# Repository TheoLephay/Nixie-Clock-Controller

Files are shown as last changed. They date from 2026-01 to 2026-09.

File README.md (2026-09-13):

# Nixie clock - Divergence Meter

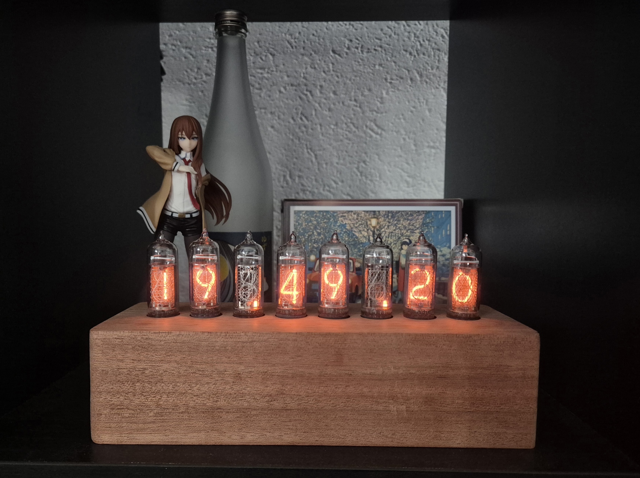
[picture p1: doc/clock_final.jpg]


I wanted to make a 8-tube design to match Steins Gate's divergence meter and to have more display capabilities.

This is build with original IN-14 (180VDC) Nixie tubes manufactured in the 70s in the Soviet Union.

## How to use

- On power on, if a wifi access point has been provided before, it will try to connect to it.
- Otherwise (if no AP, or if connection fails) it will display blinking dots and it will turn into an access point named "ESP32_Nixie".
  Connect to it, open the clock's IP on a web page, and provide wifi SSID and password. The clock will then
  try to connect to the provided wifi AP.
- It will start displaying the time. You can press the toggle swith (long or short press) to change modes.

## How to build

There should be most of the design files for software and hardware to reproduce it.

Except:
- Tubes that I bought on Ebay
- The BOM is not exaclty complete but all the electronics to build the PCB are there. What's missing is
    - the Molex ribbon cables (check the reference of the connectors and find the matching ones)
    - few pin headers and jumpers
- The case that is home made with some very specific tools.

---

## Hardware

See hardware/*.pdf for the design sheet and layer views. All Kicad design files should be present to build them and the gerber files.

key facts:

- Made for 8 IN-14 tubes
- HV DCDC generator made on board, based on [this design](https://nick.desmith.net/Electronics/NixiePSU.html)
- HV open drain shift registers HV5622 (no multiplexing)
- ESP32C3 module
- Most of the components are solderable with a soldering iron (except the ESP32 because of the pads underneath, heat gun or hot plate required + stencil)

#### Version 1.1 updates:

Fixed HV5622 footprint, used a bigger DCDC FET (Vds rated >250V), Reduced GPIO9 cap size to avoid starting in DL mode, and added PD resistors to the level shifters' NFETs.

### Issues

The feedback line of the DCDC is picking up noise which creates a visible dimming oscillation at around 20Hz (50Vpp). At high load it even makes the DCDC saturate.
I fixed it by adding a small cap (100pF) on FB pin. 0603 size is perfect to sit between SHDN and FB pins of the MAX1771.

My DCDC has only a ~70% efficiency which is not super good compared to the original design (85%), I probably did a poor layout job. But in practice it does not matter since currents involved are small.

## Software

key facts:

- Using ESP-IDF VSCode extension v5.2.1
- Programming via UART (two buttons on the board to get the ESP in download mode)
- Has a "maintenance" routine timer to cycle the cathodes lit to prevent cathode poisonning.

More modes to be coming (with a connected weather station it will be able to display temp/HR...).

- main/src/Connectivity.c - wifi state machine, mDNS & SNTP setup.
- main/src/HV5622.c - Bit banging shift register driver.
- main/src/ModeSwitch.c - Driver for the toggle switch.
- main/src/NixieDisplay.c - simple driver to display data on the 8 tubes using the shift registers.
- main/src/NixieHttpServer.c - Web control page
- main/src/SmartClock.c - core logic of the clock to display time, handle different modes.
- main/src/Storage.c - NVS wrapper for storing wifi credentials.

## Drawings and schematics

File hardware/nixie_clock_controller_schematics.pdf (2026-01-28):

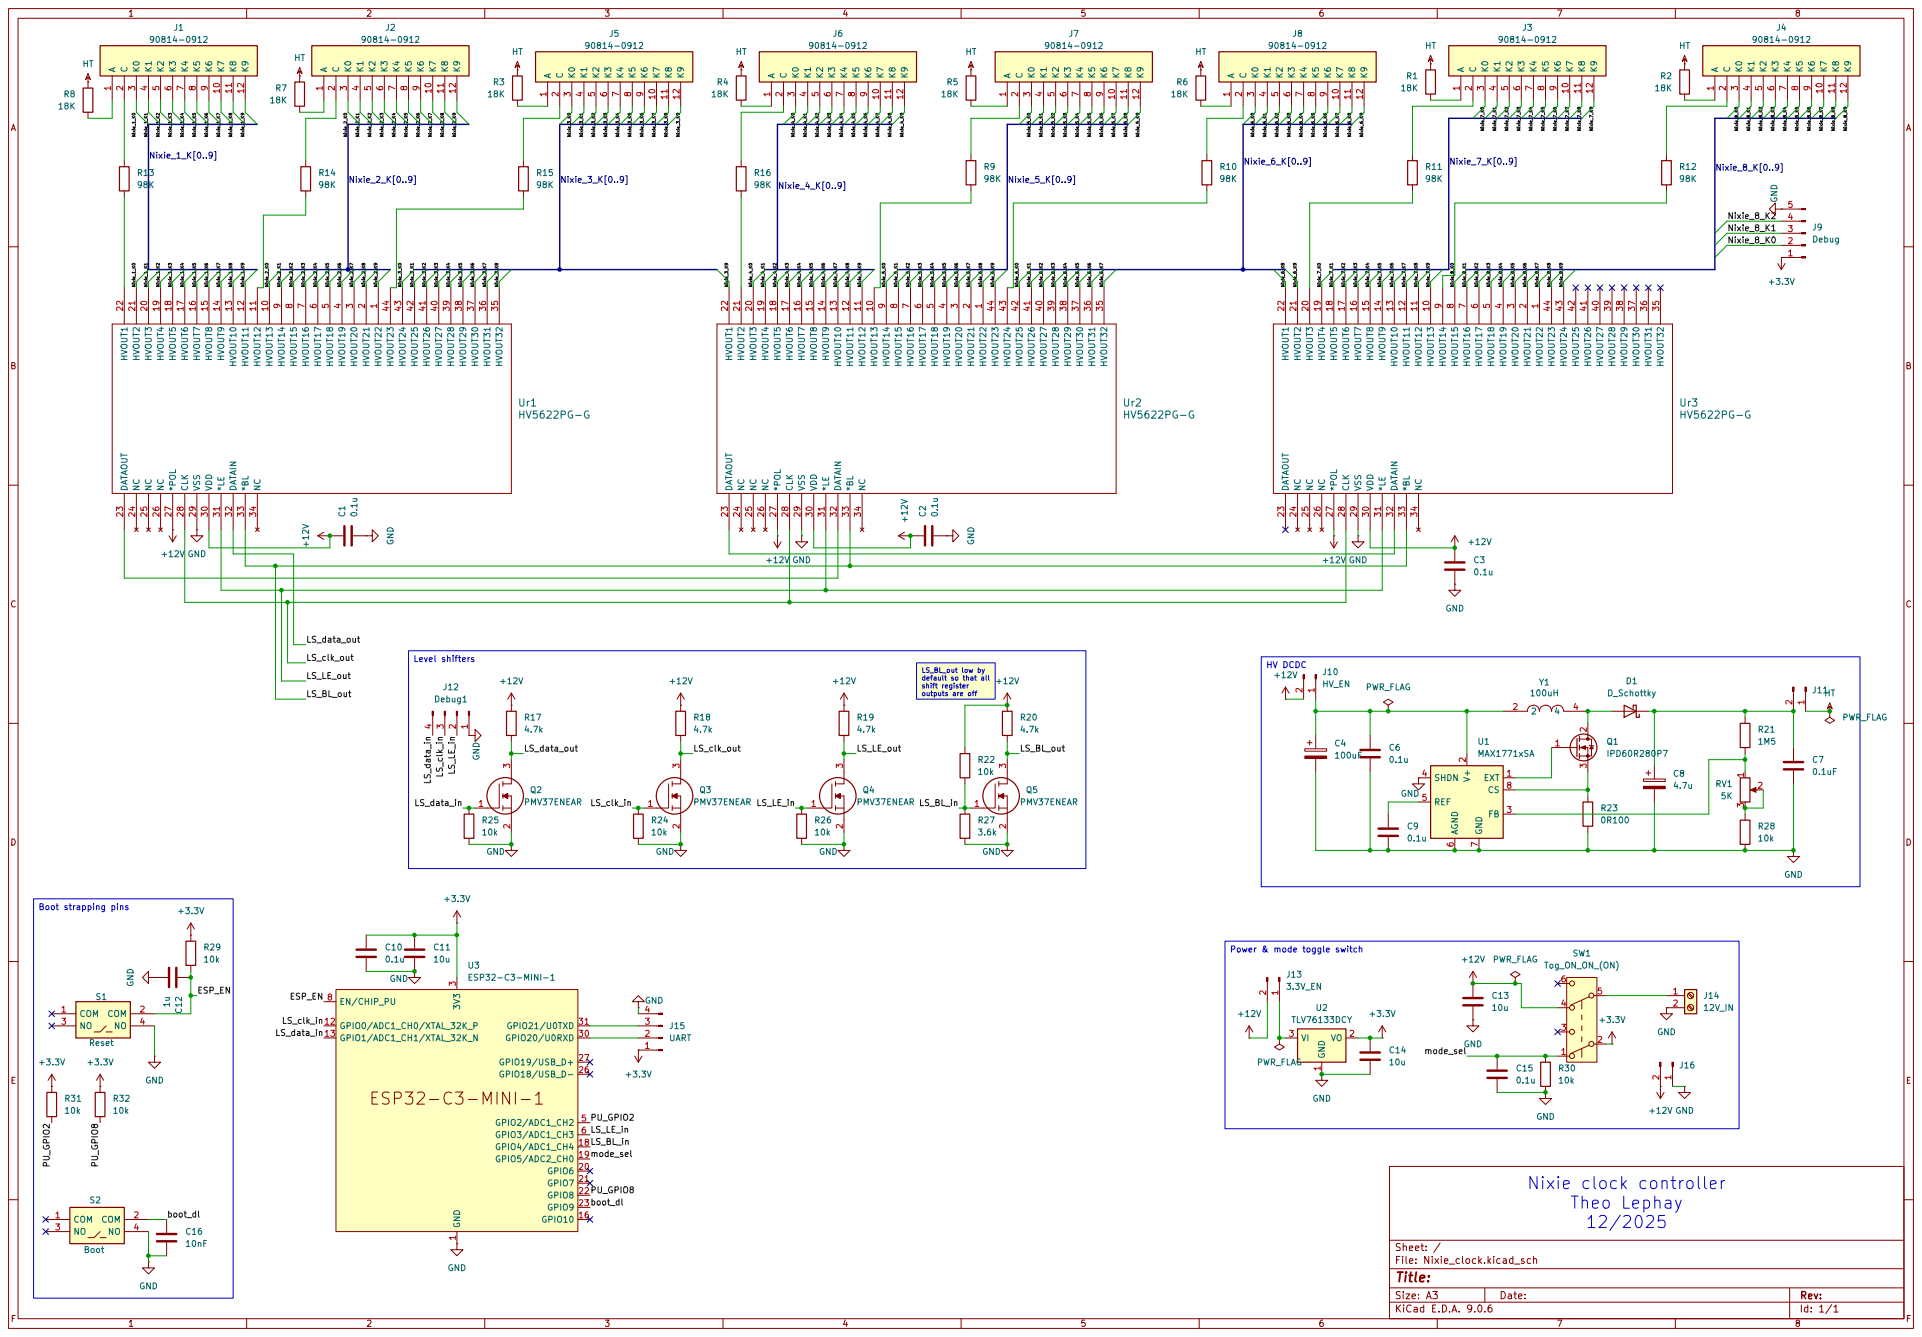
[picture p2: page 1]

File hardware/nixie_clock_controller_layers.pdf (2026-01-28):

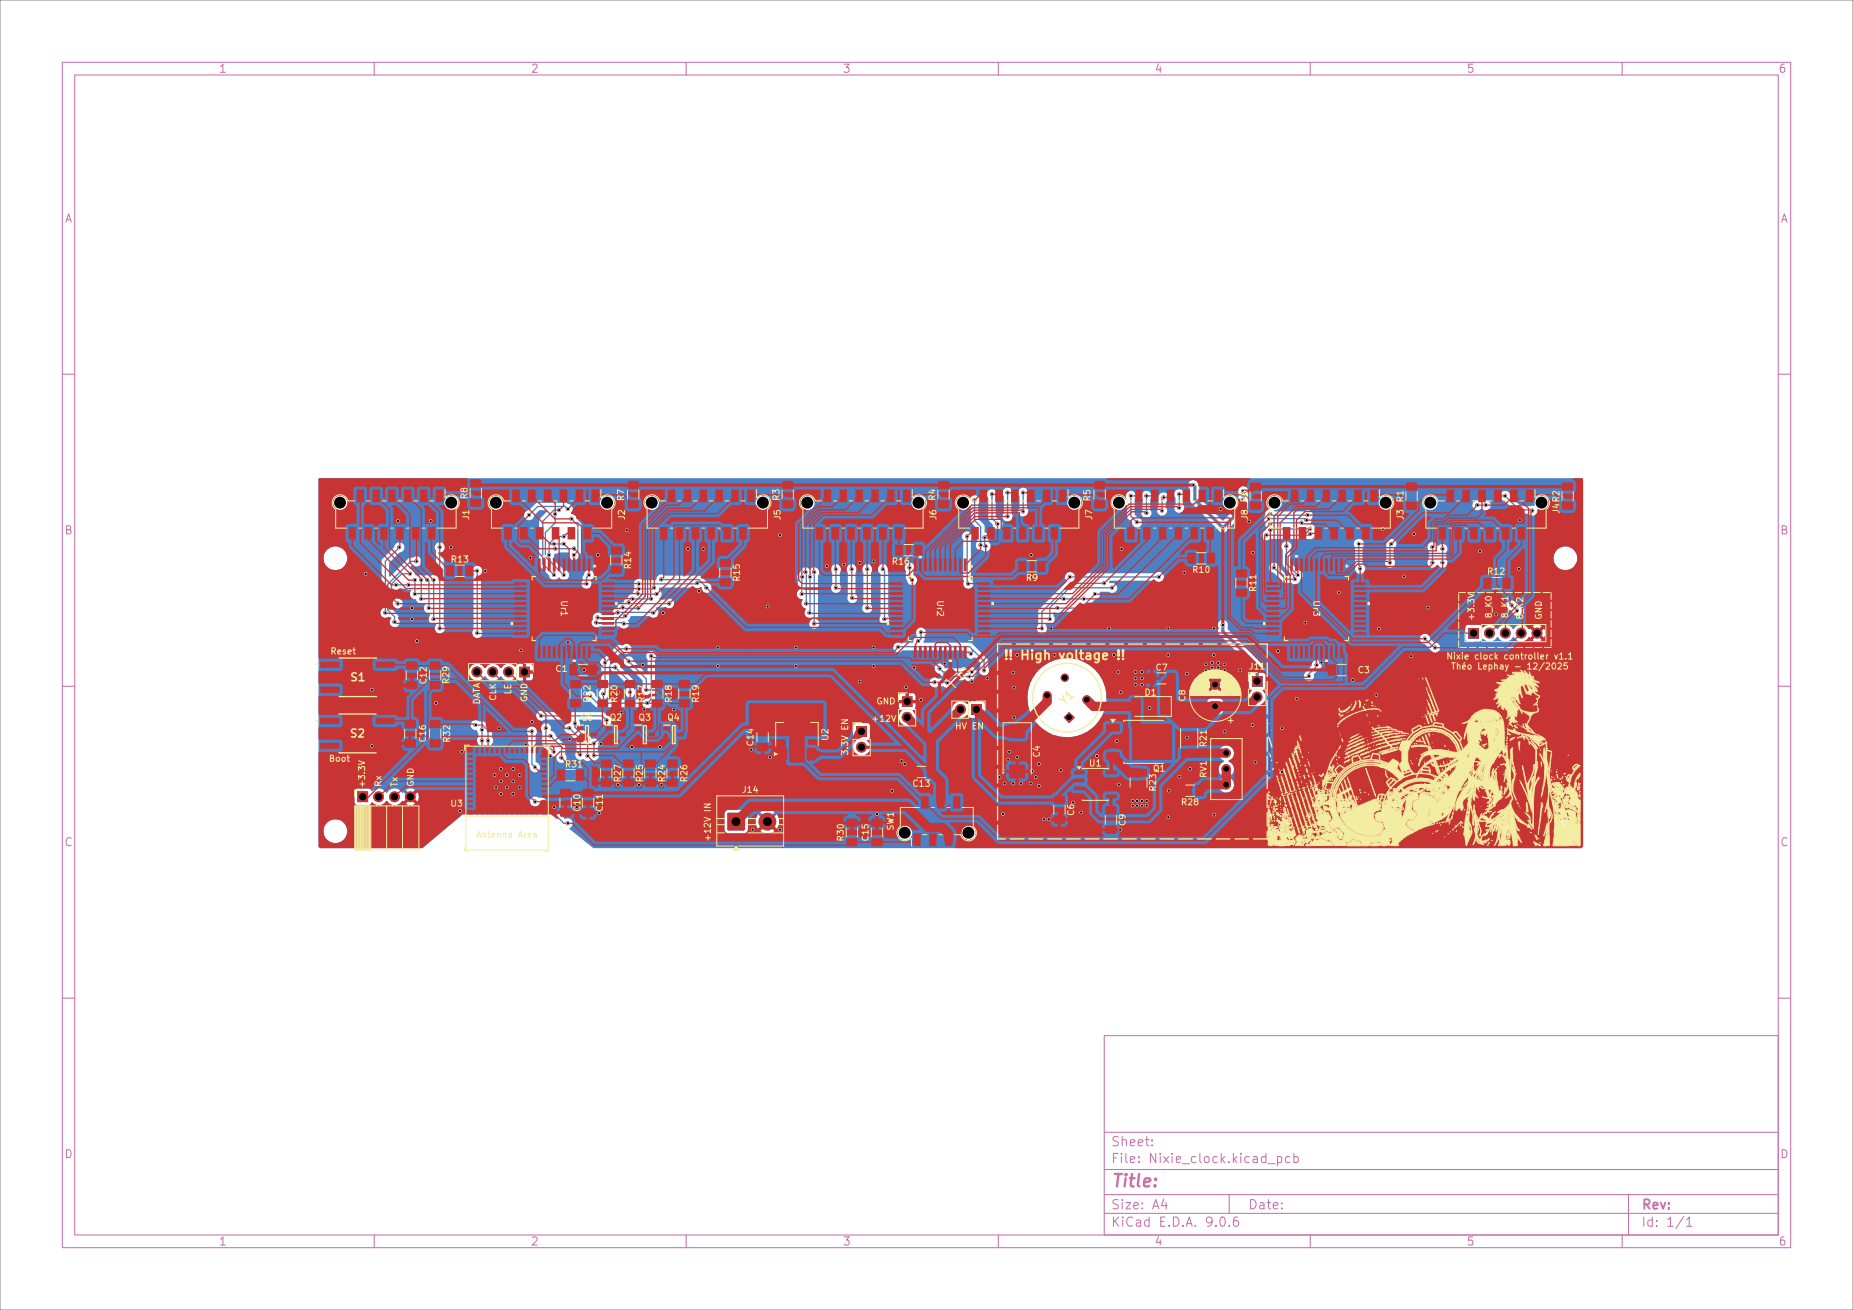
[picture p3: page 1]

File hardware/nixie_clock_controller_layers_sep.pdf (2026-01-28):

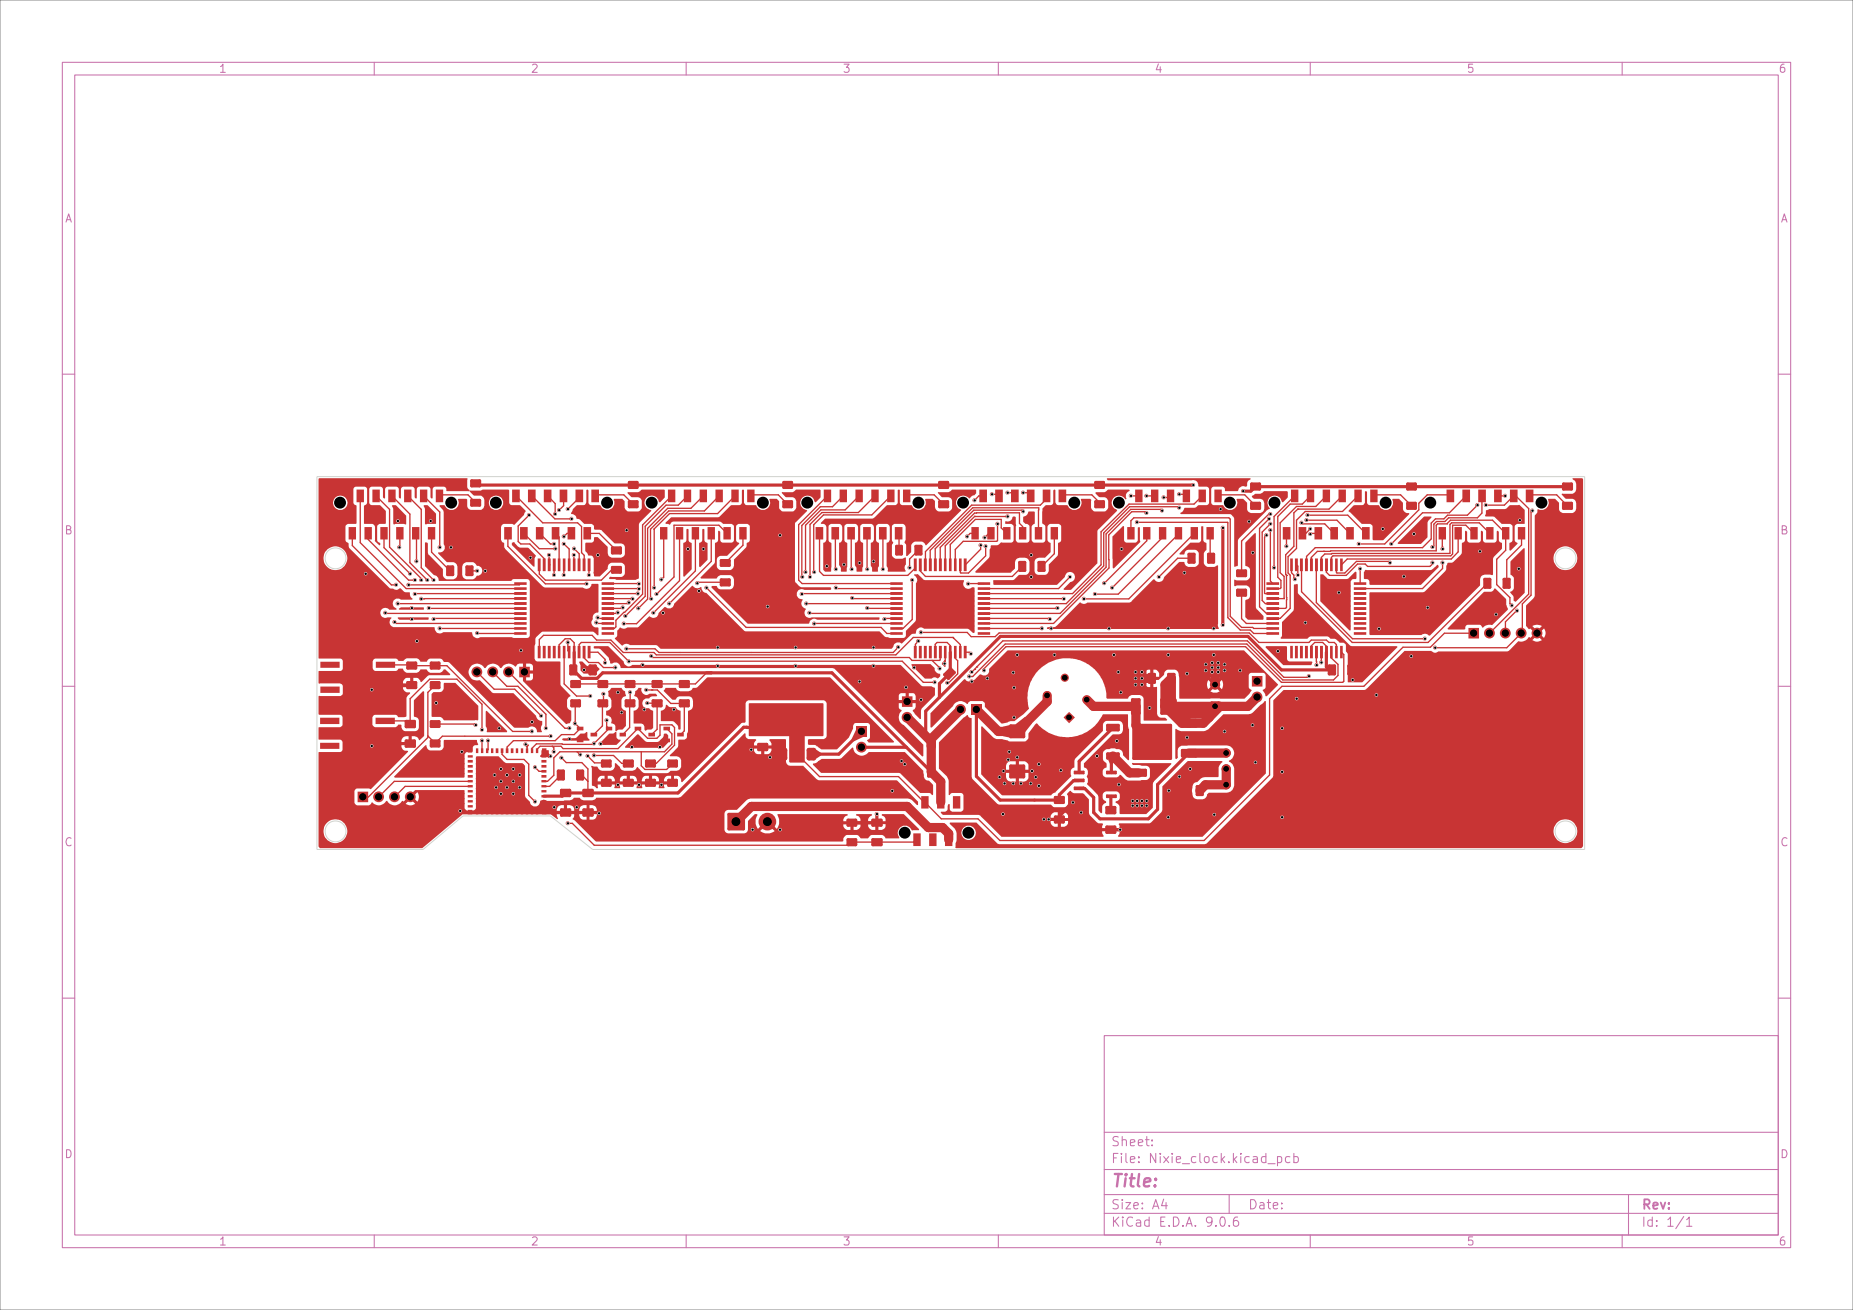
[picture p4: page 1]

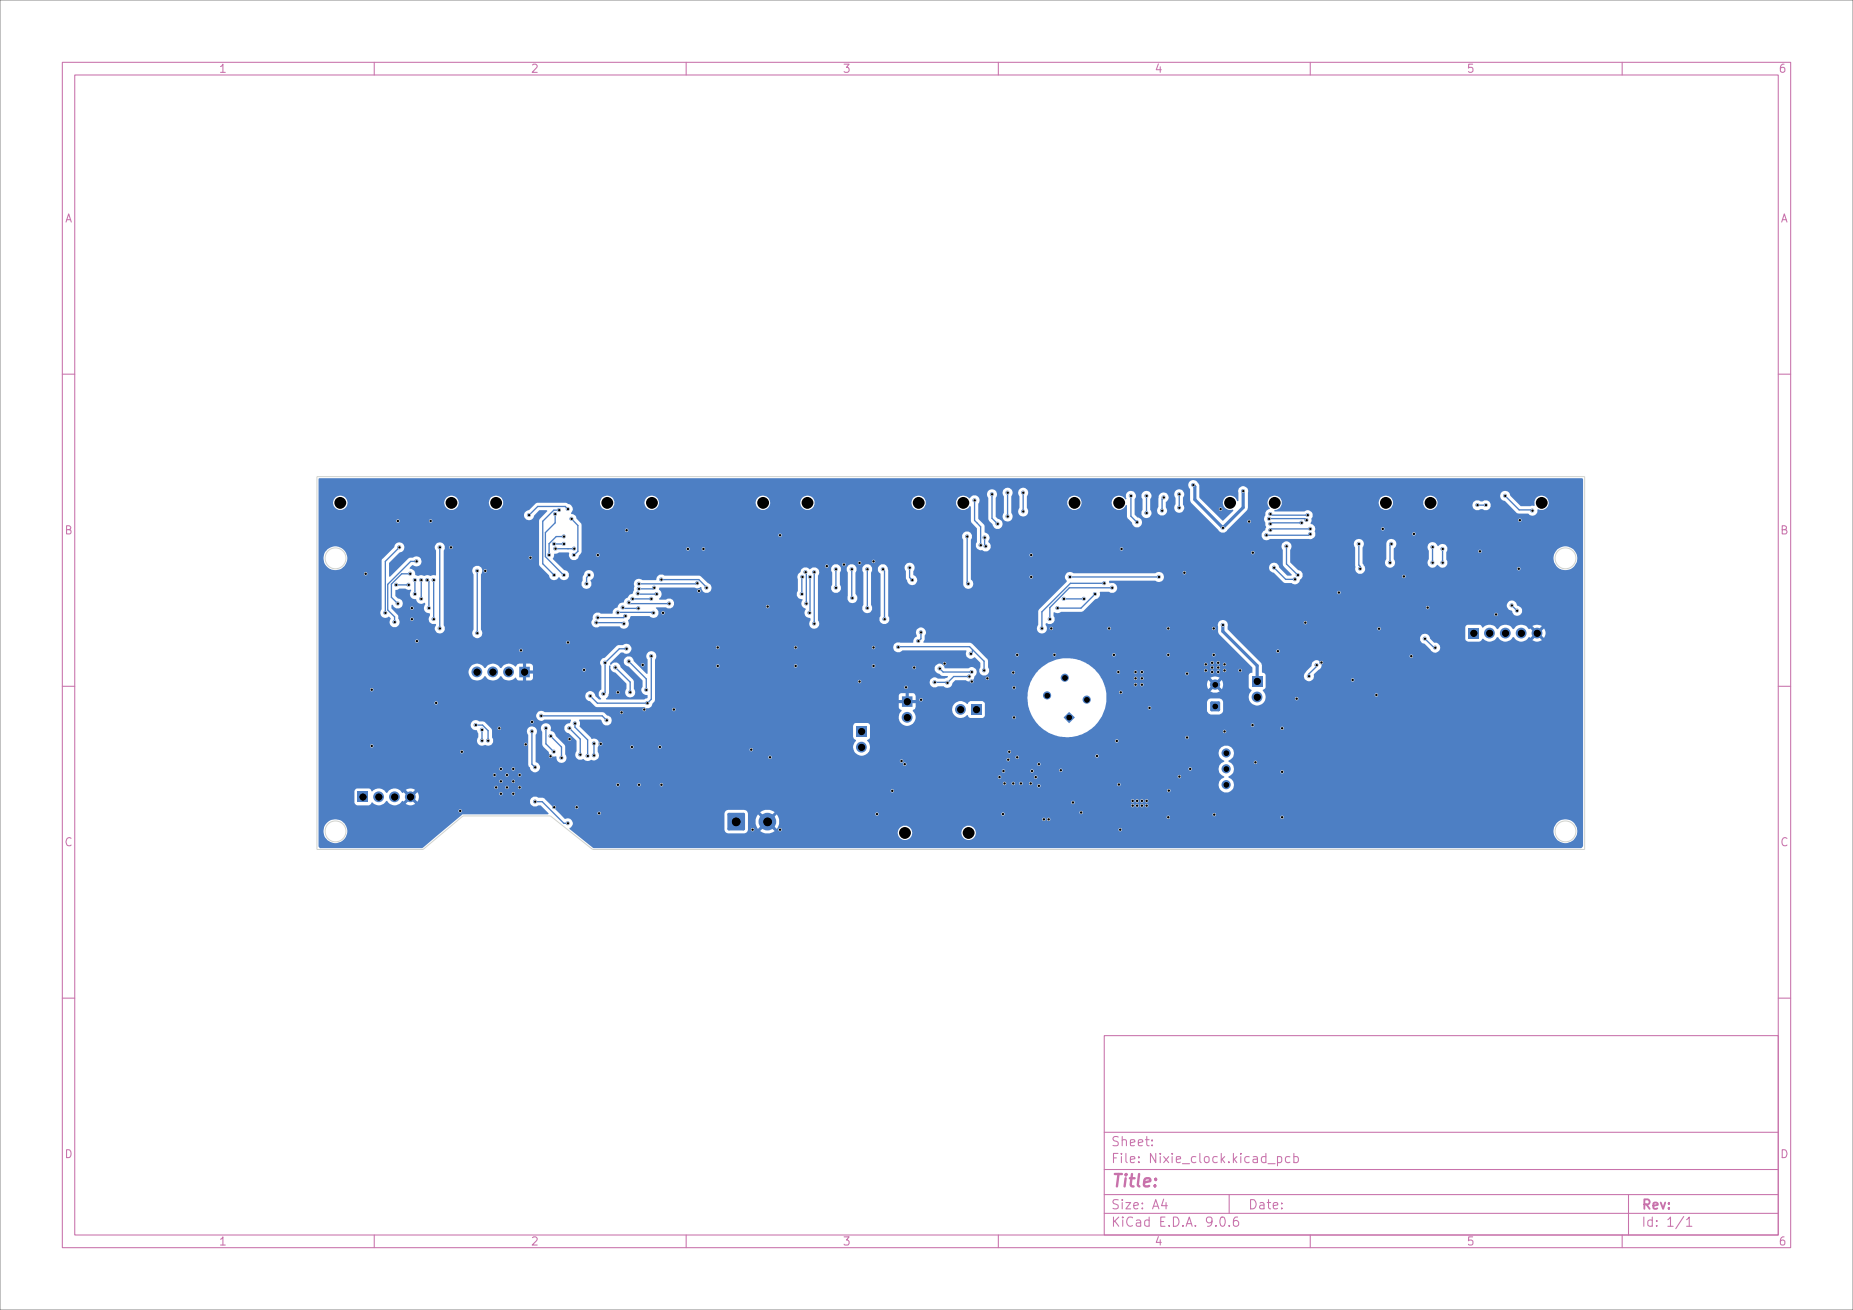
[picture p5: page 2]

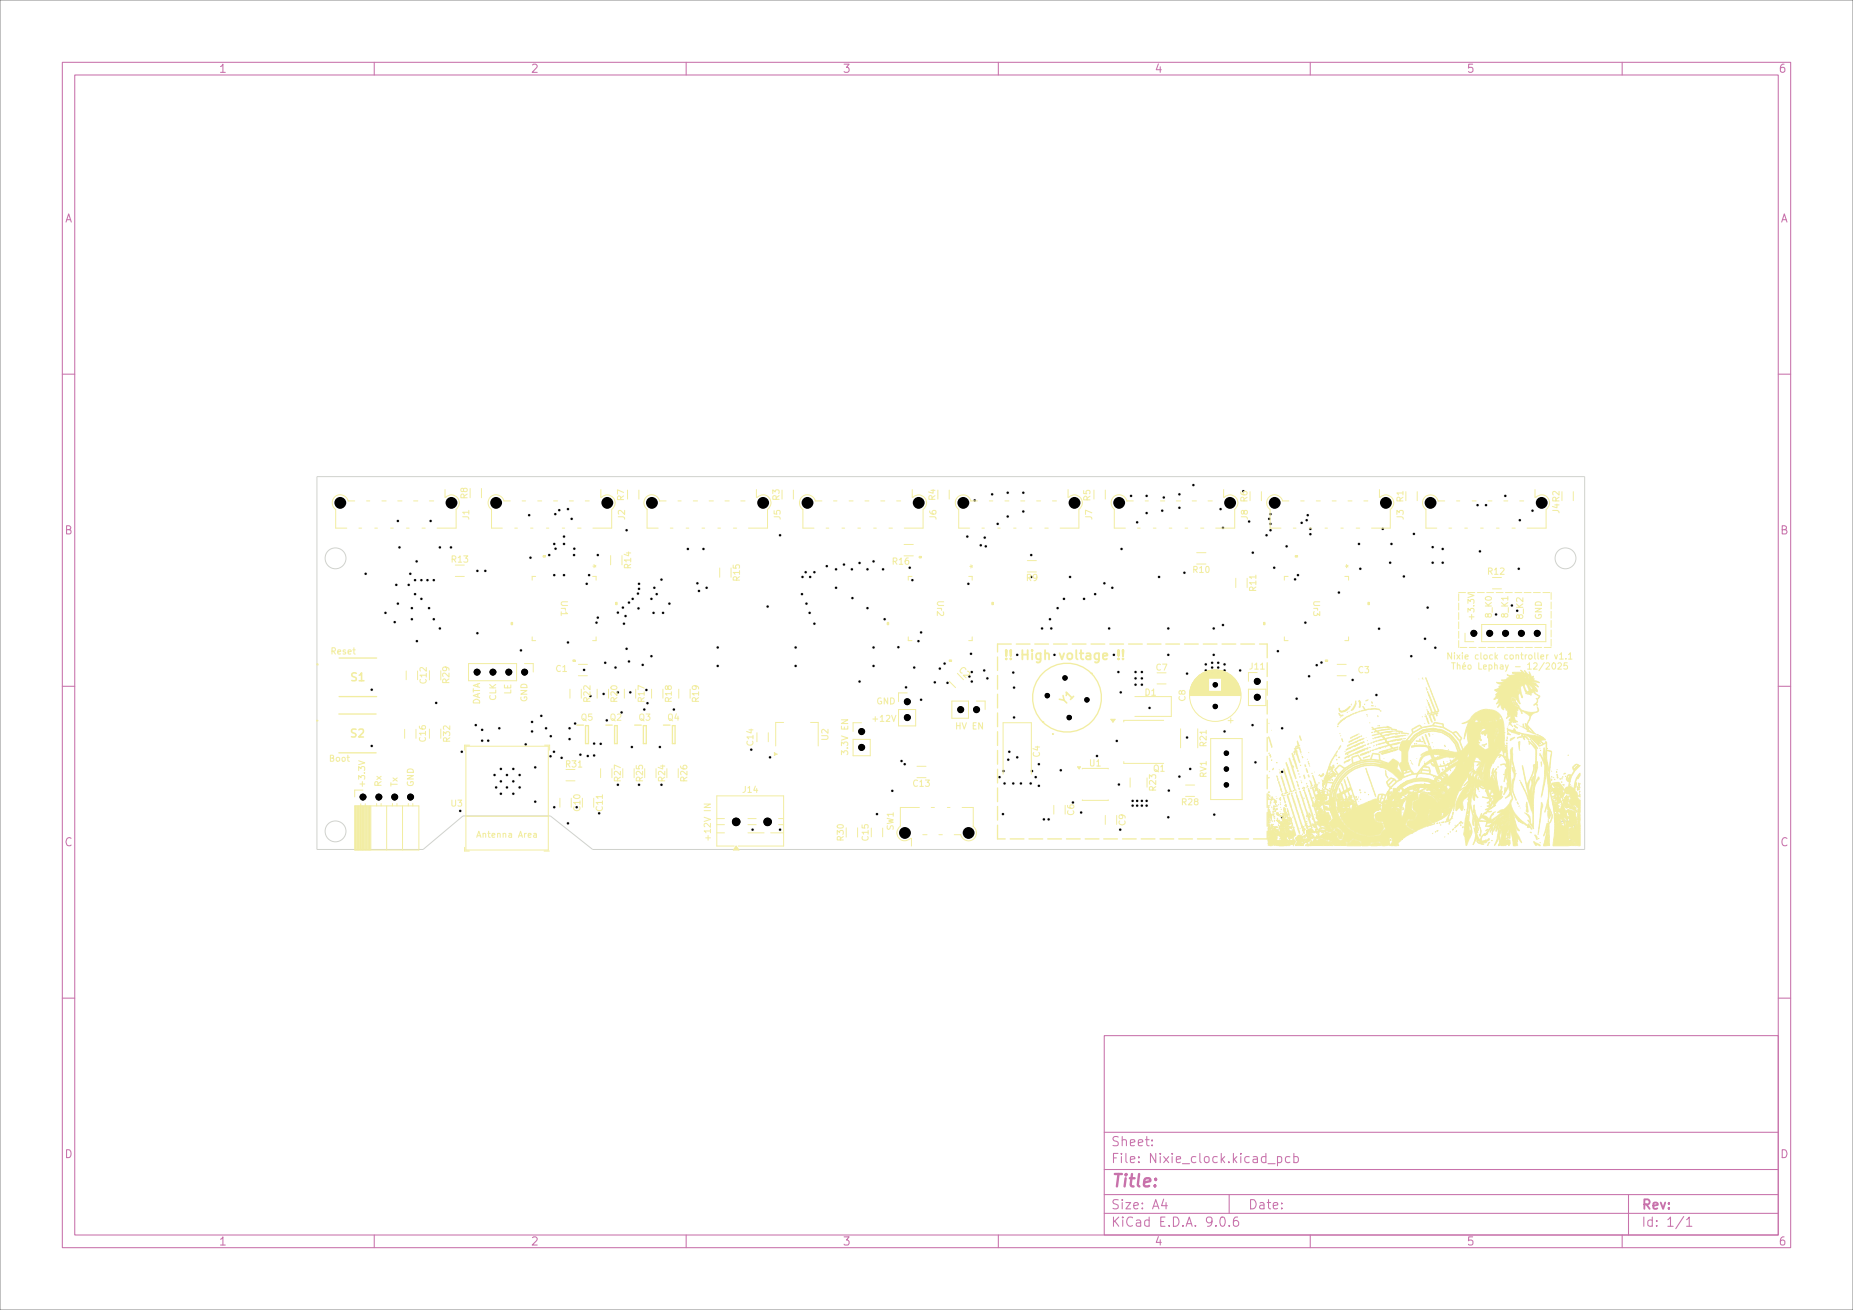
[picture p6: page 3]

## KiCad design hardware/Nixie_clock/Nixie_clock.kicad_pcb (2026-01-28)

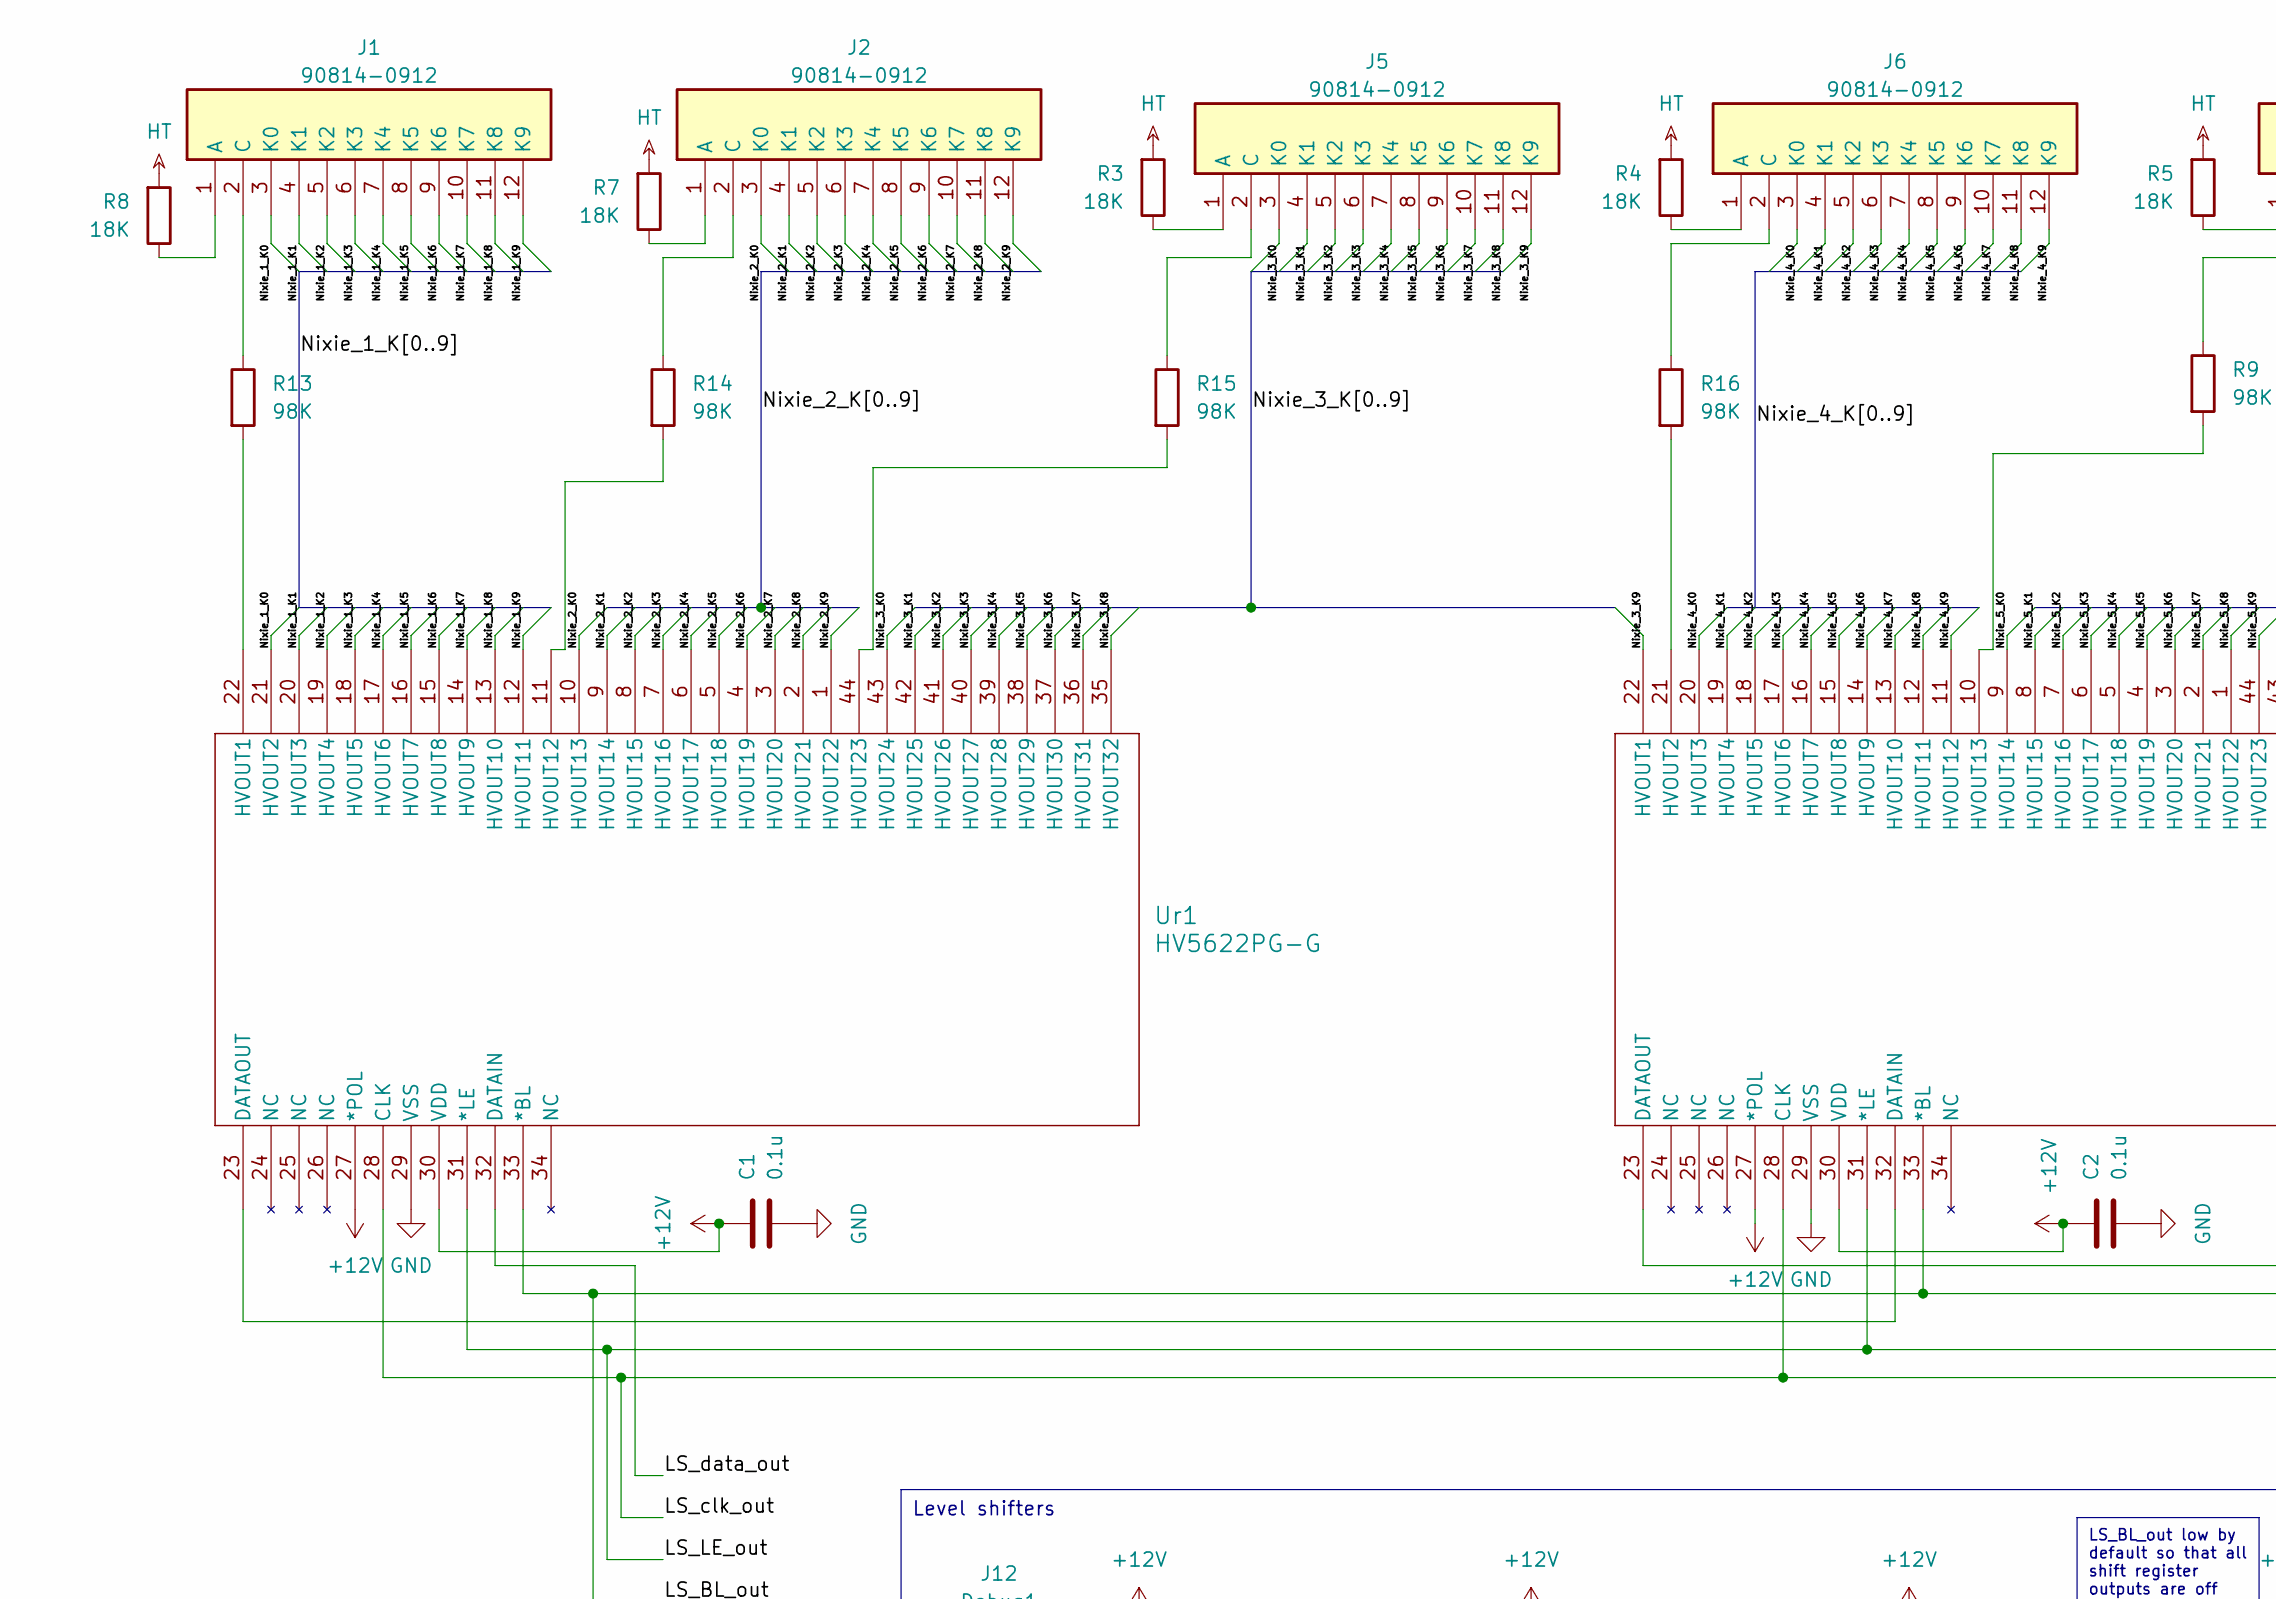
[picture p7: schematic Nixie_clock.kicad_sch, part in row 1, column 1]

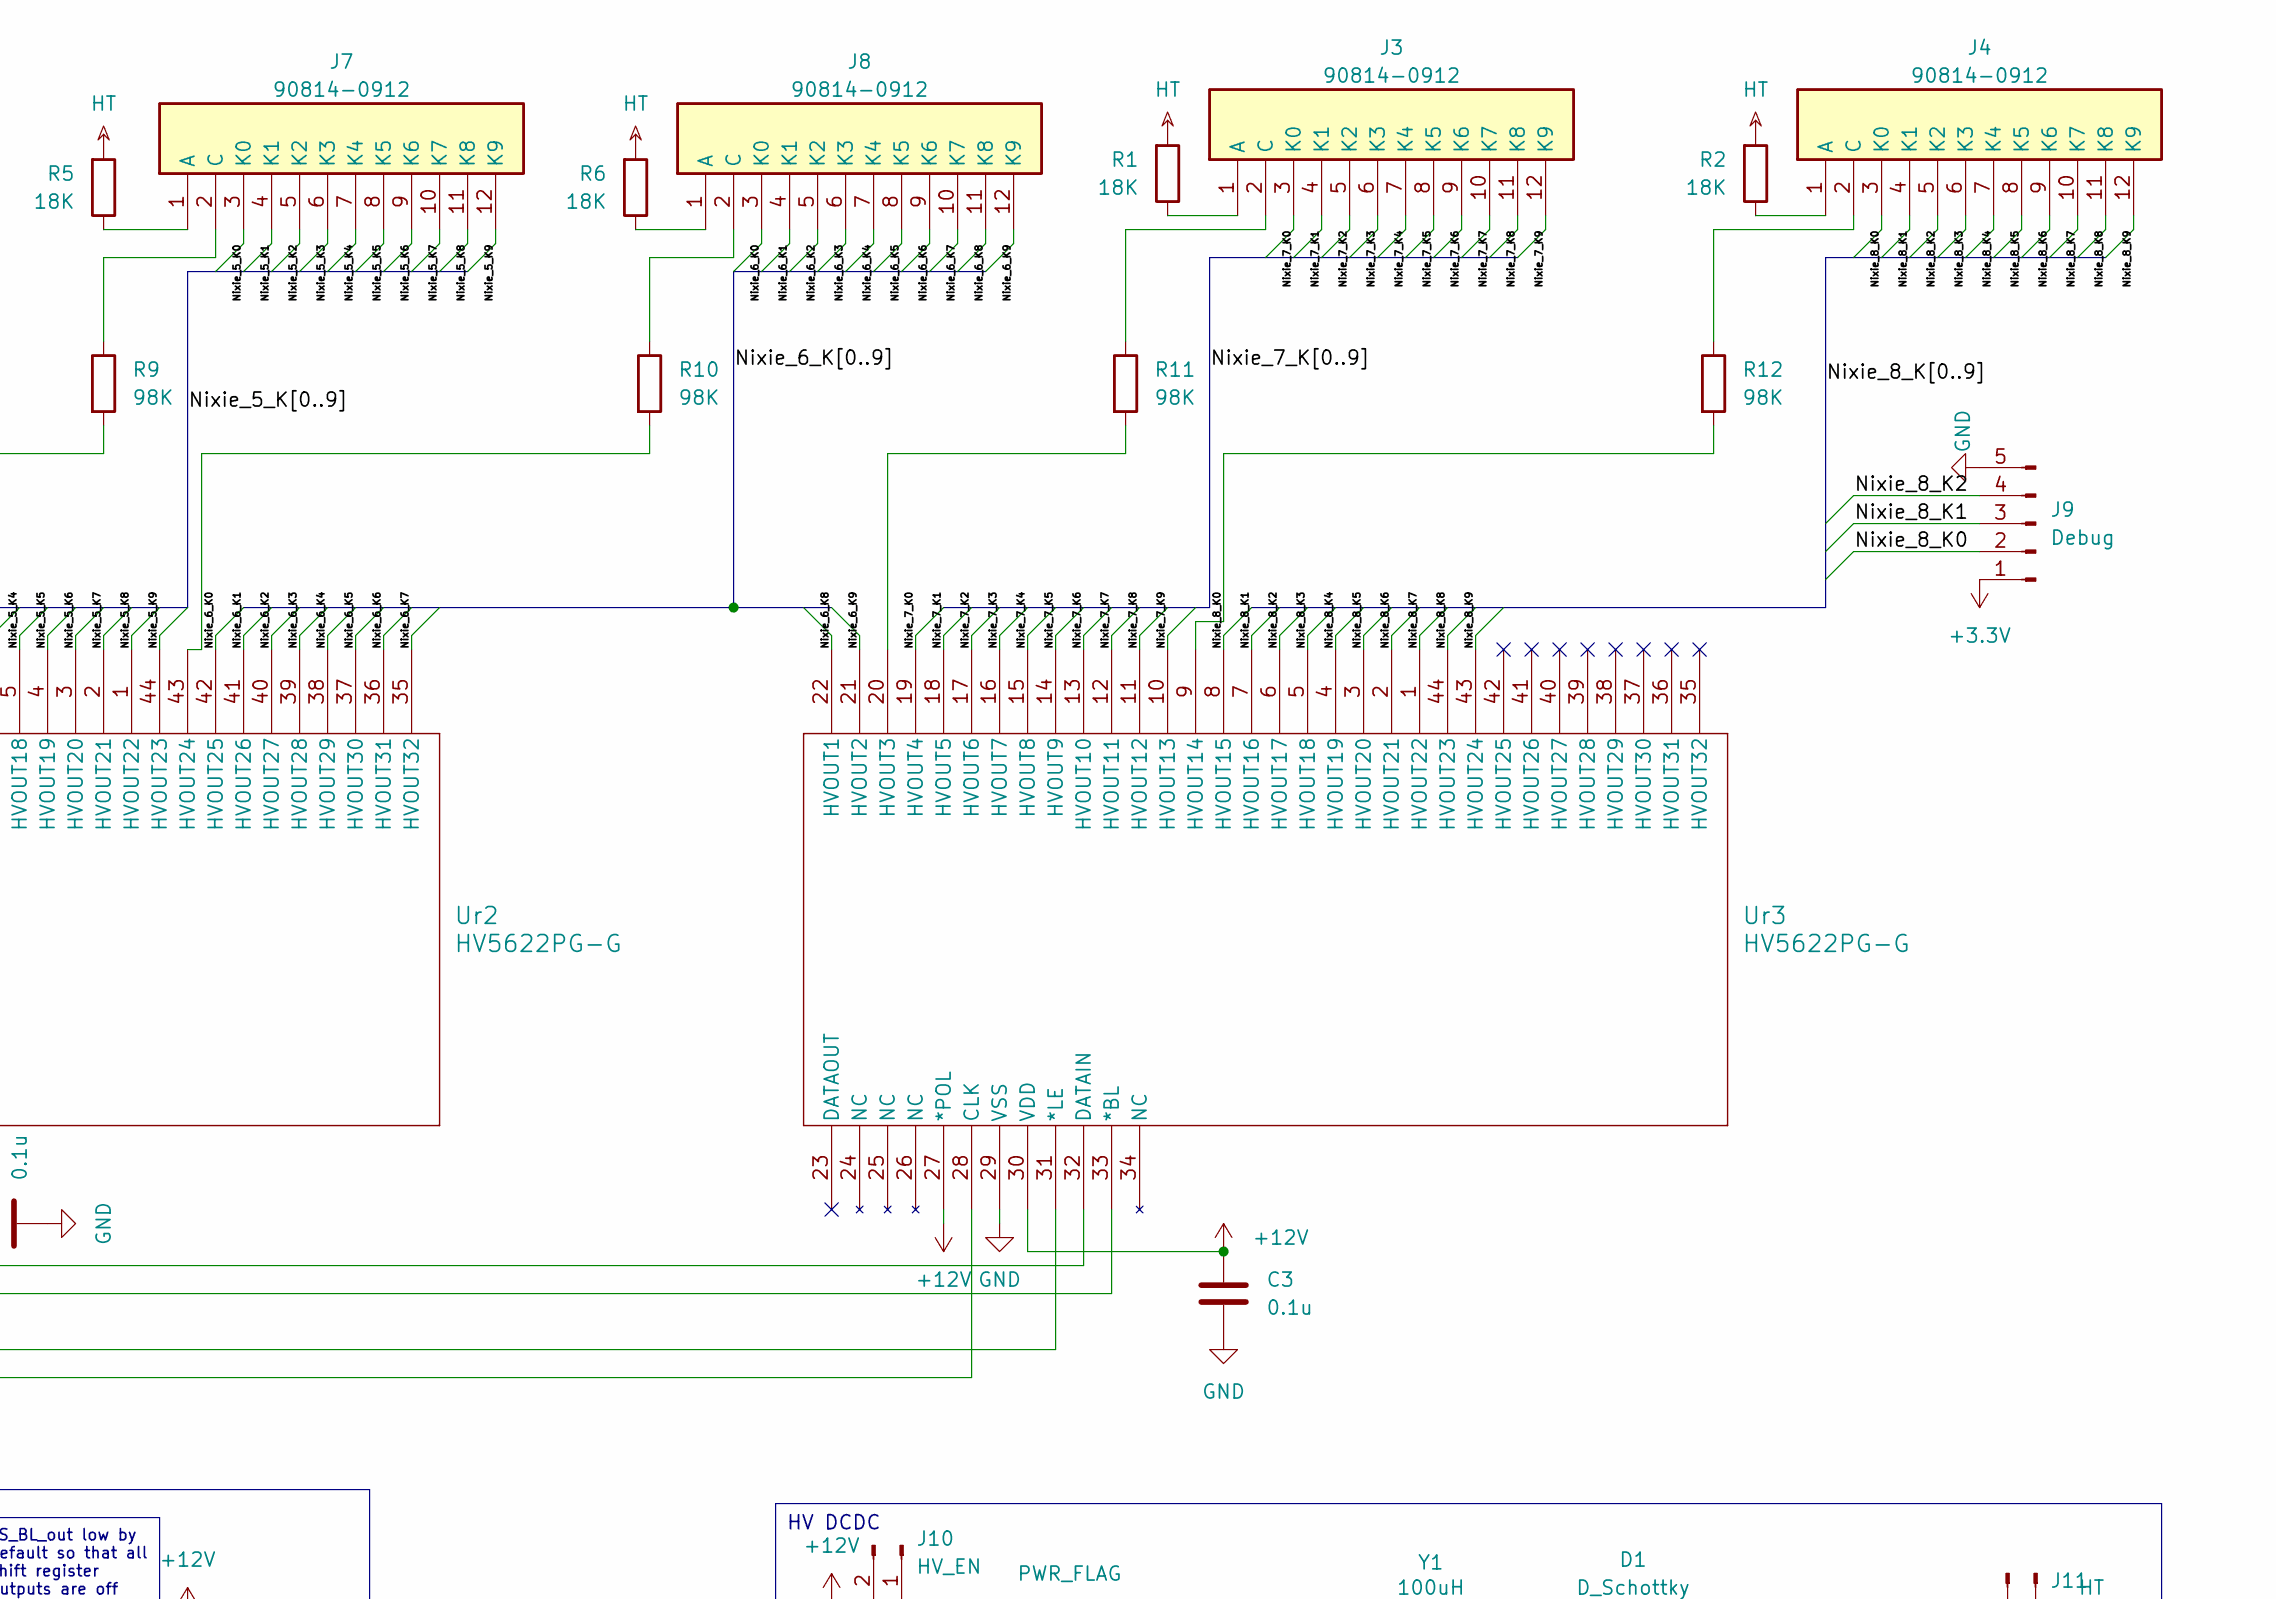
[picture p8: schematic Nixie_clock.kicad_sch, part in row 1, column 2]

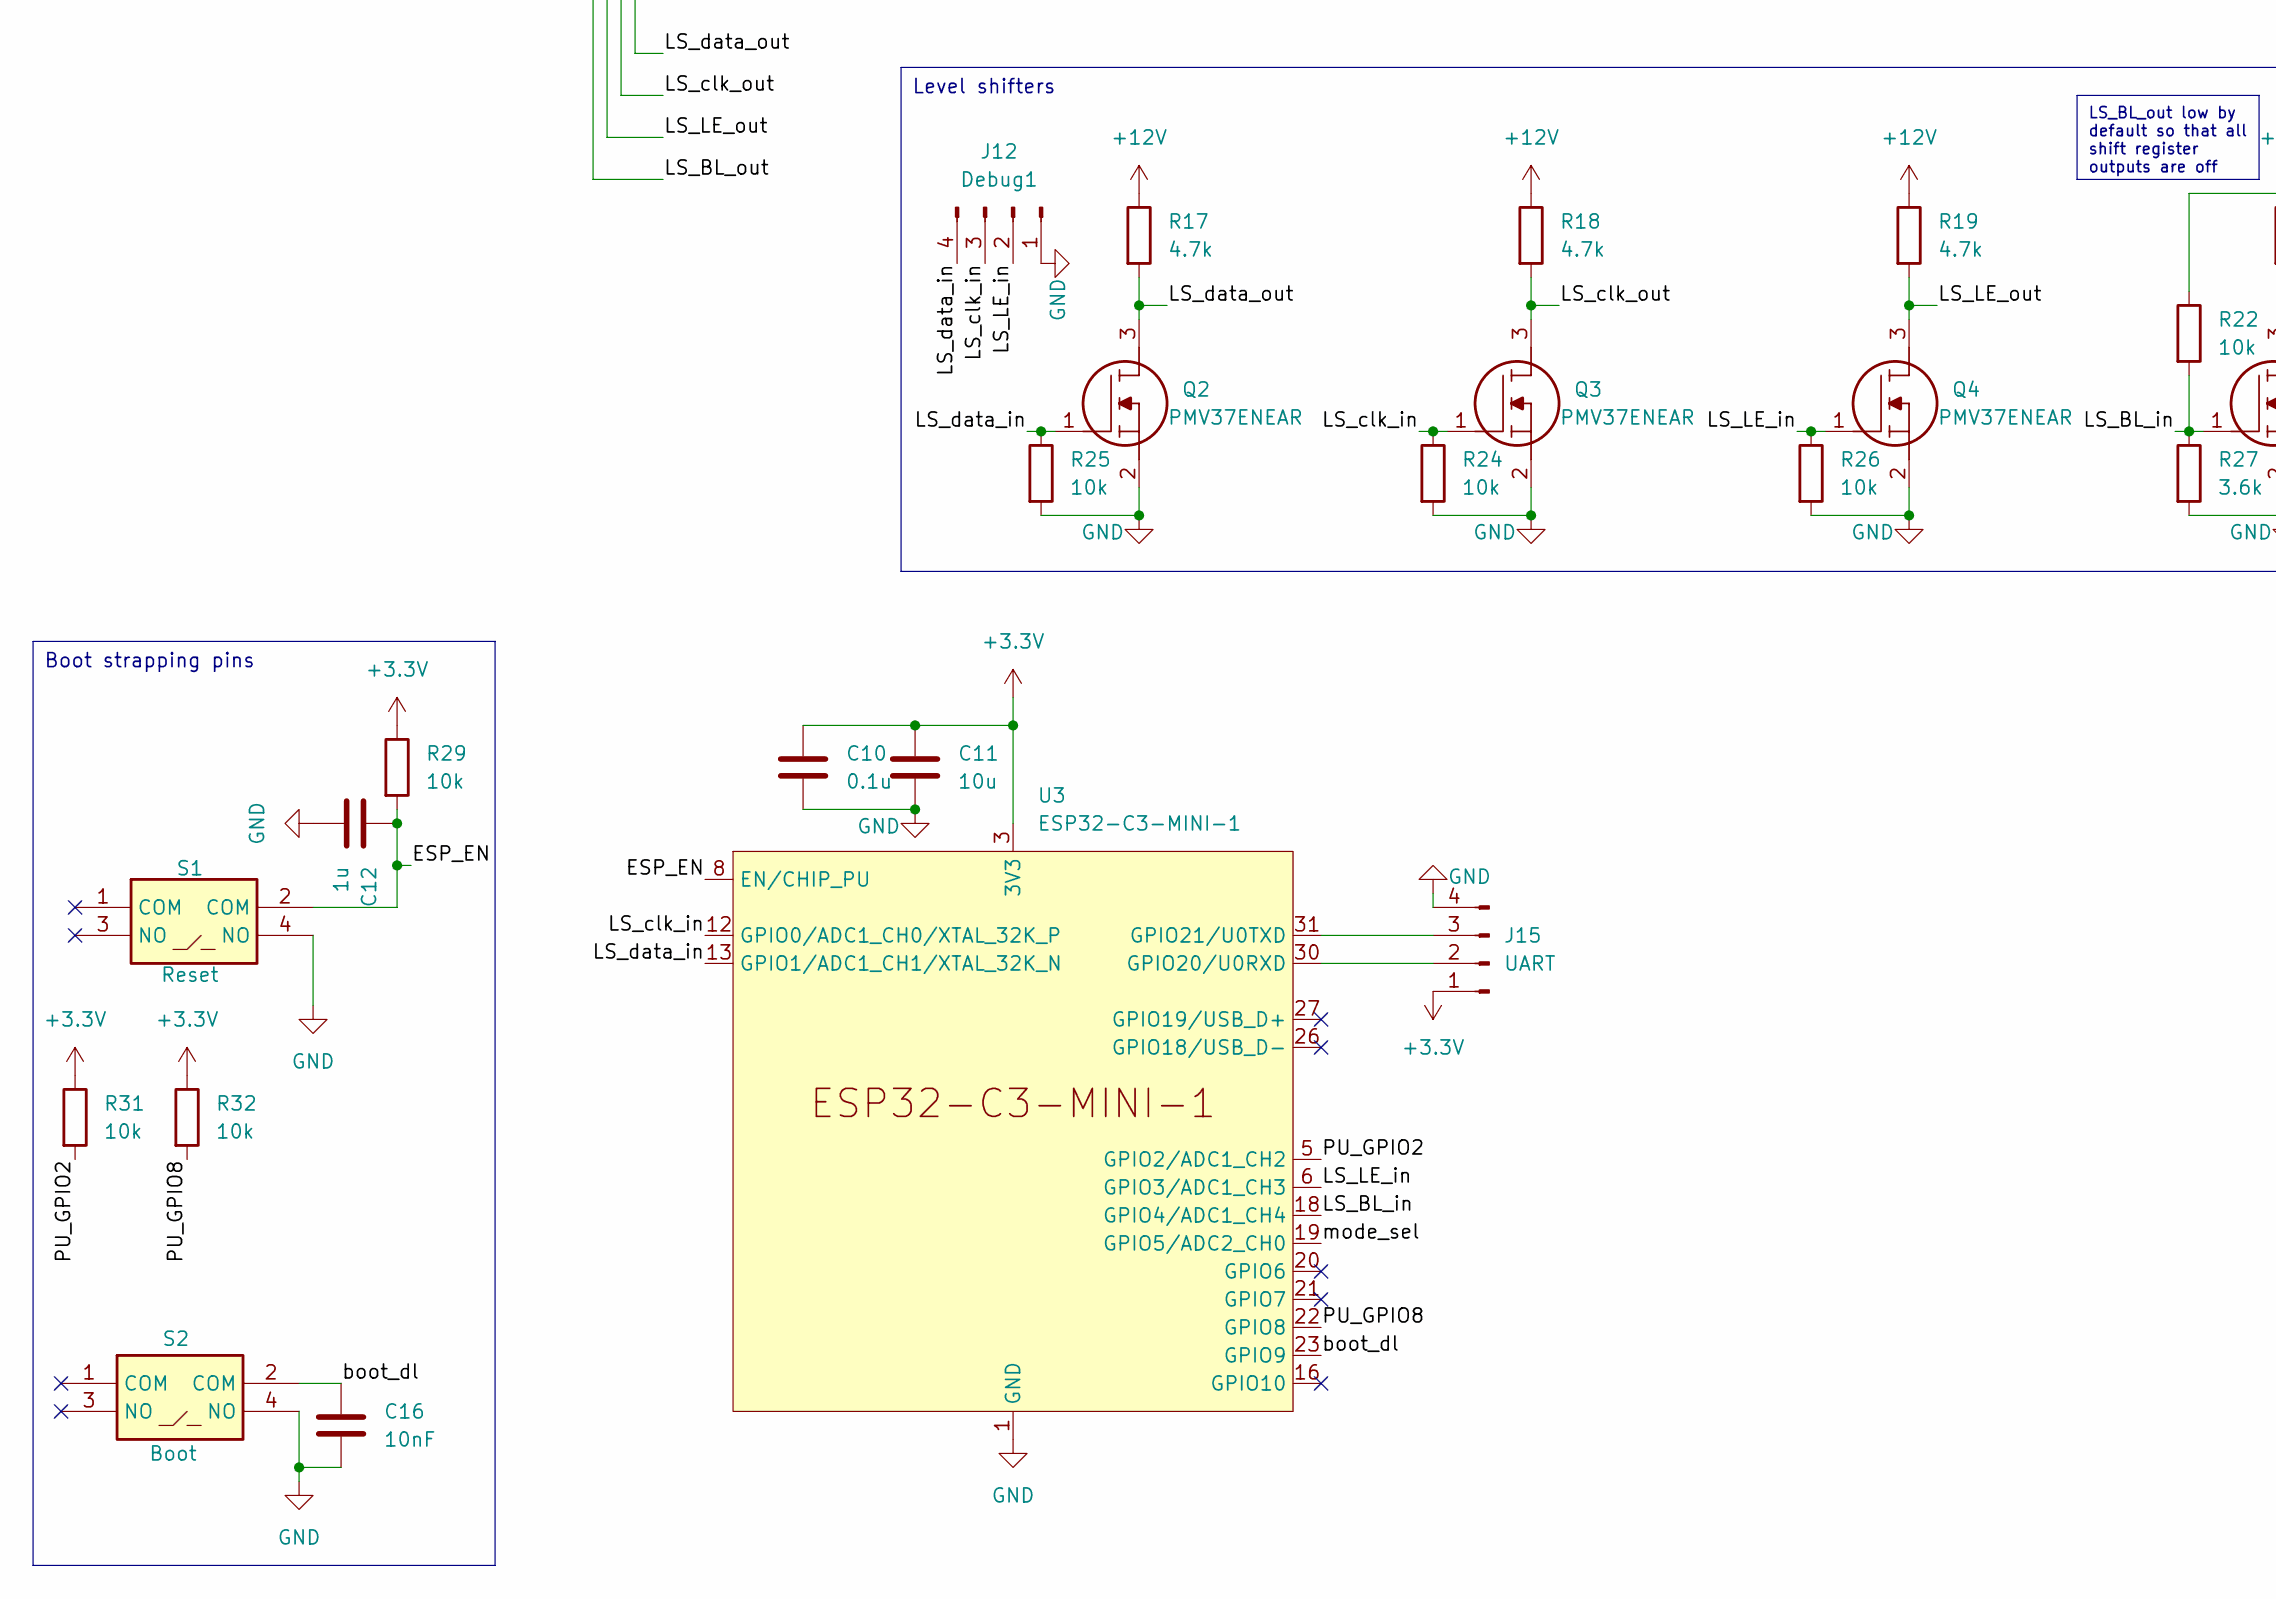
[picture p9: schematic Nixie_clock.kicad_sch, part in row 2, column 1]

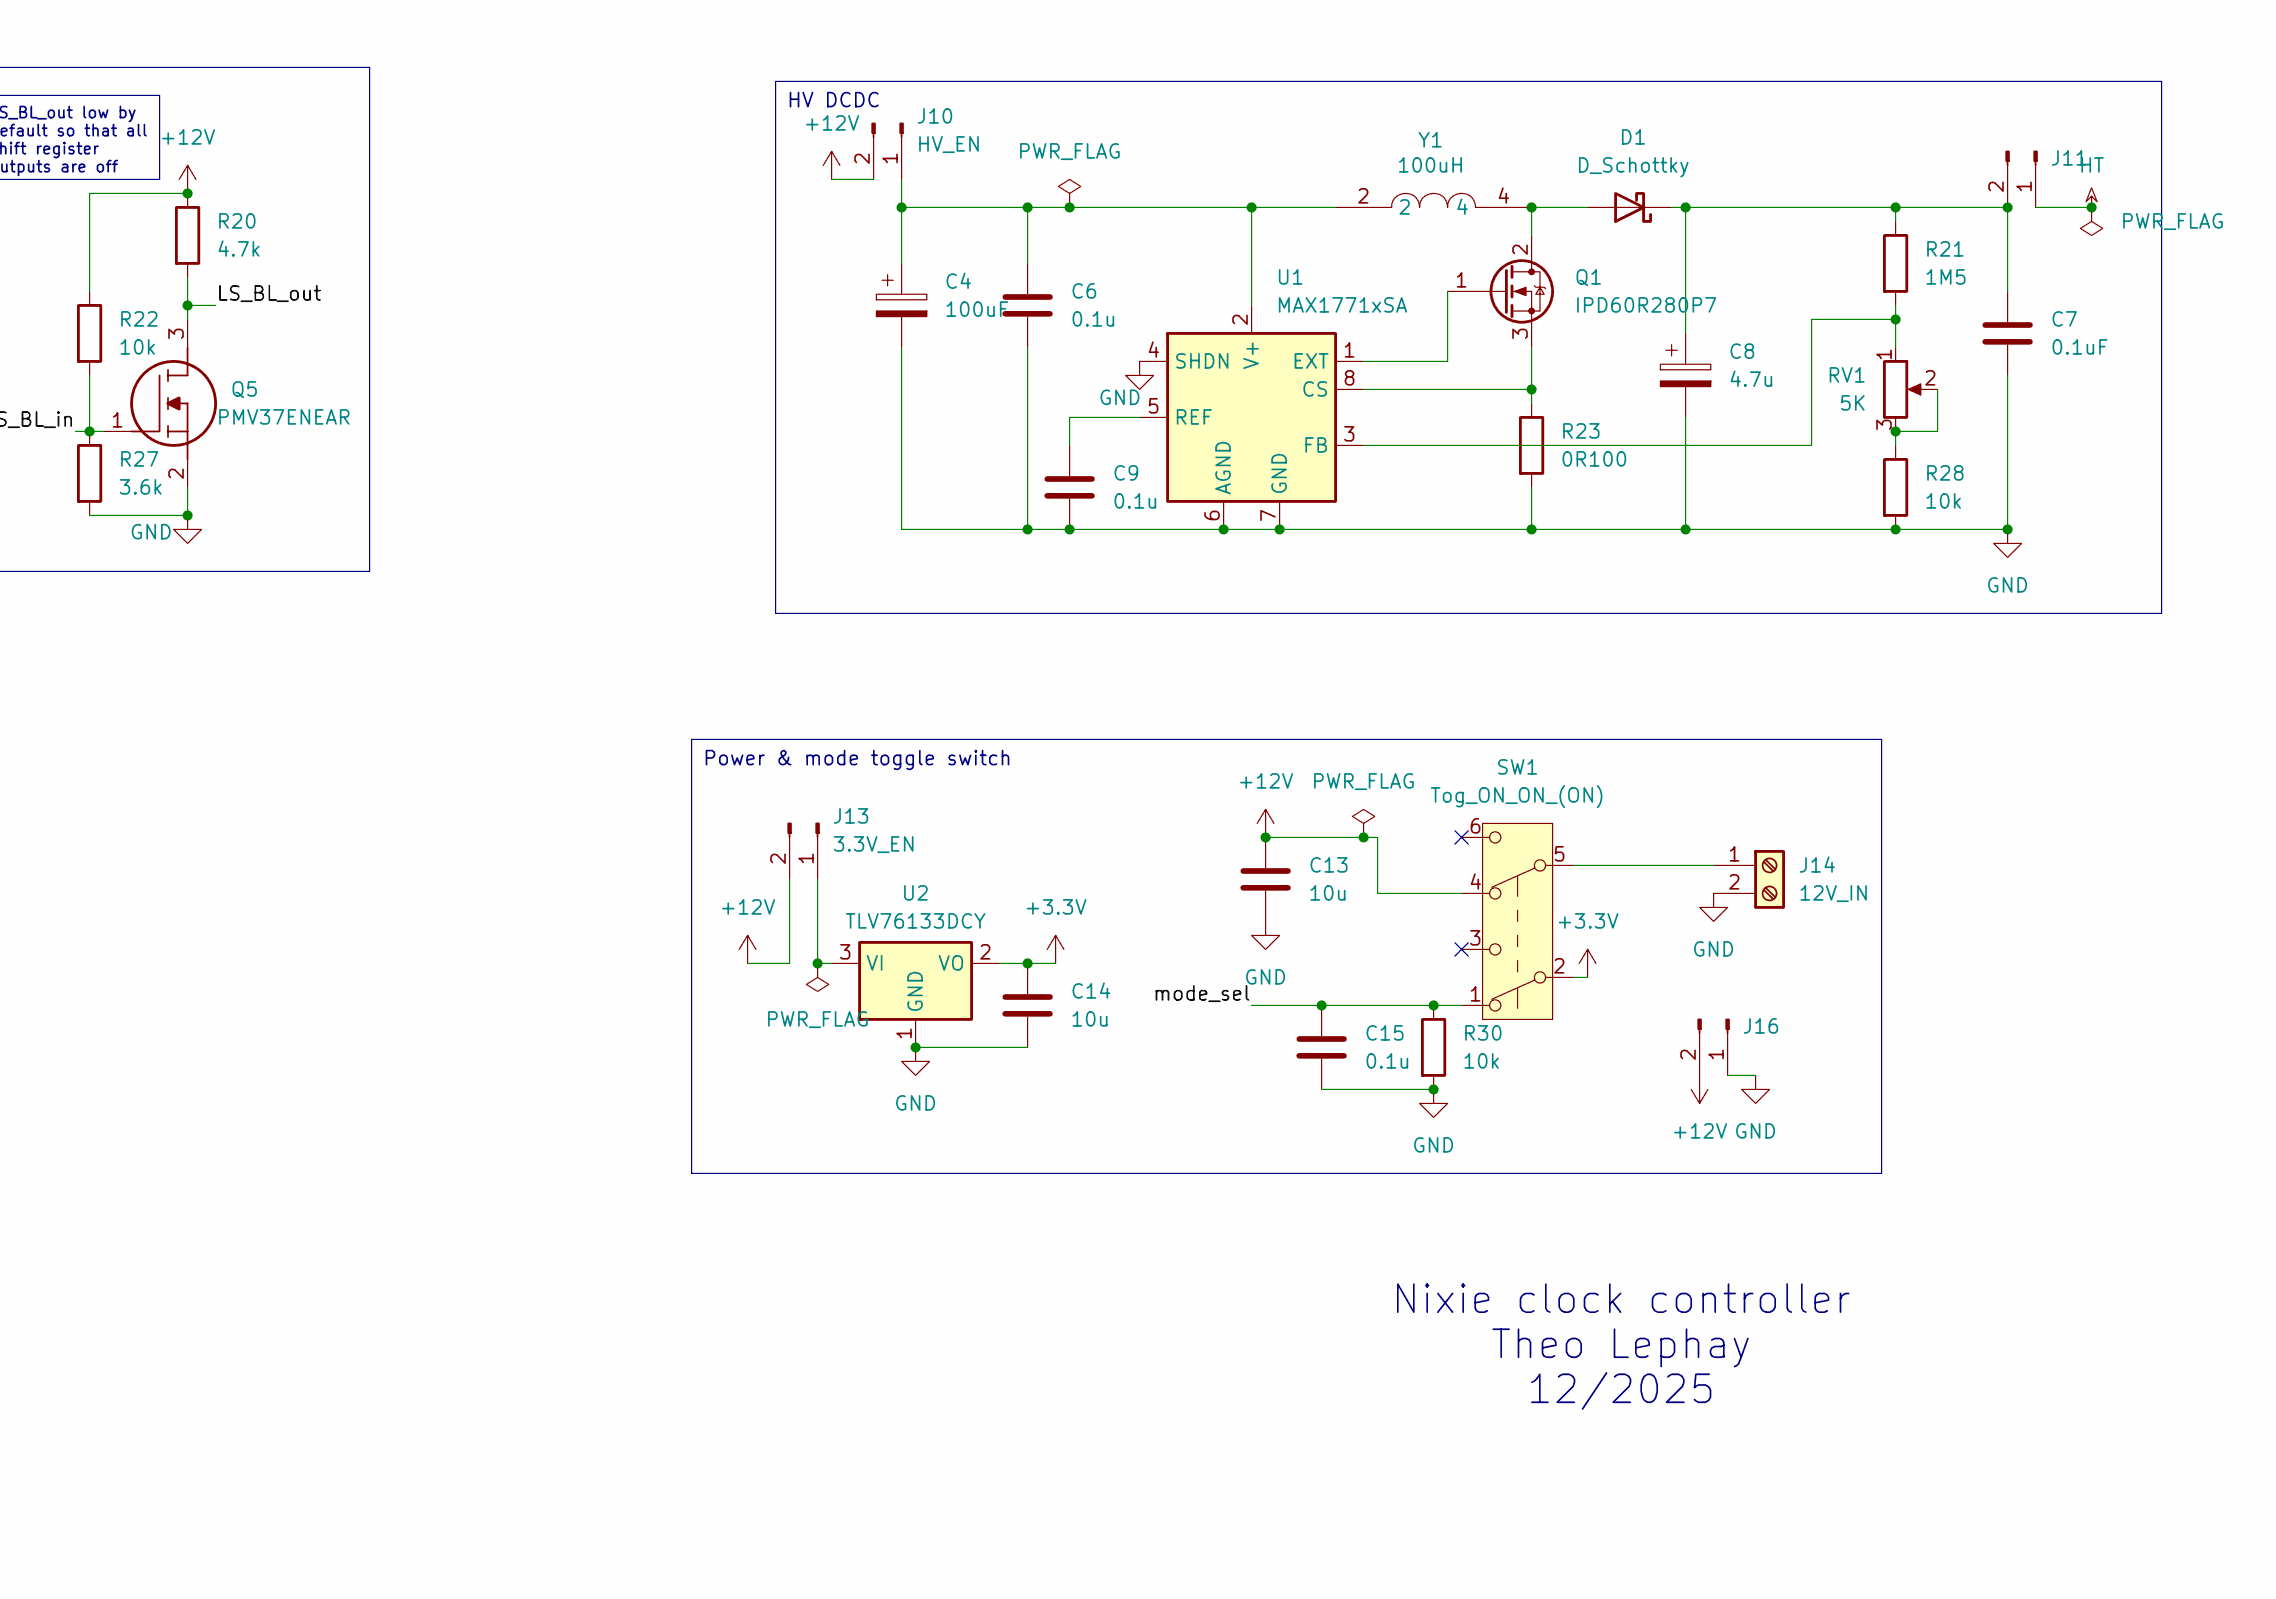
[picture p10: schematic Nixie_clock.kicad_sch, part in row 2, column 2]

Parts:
C1, C2, C3, C6, C9, C10, C15: 0.1u; C_1206_3216Metric_Pad1.33x1.80mm_HandSolder
C4: 100uF; CP_EIA-7343-31_Kemet-D_HandSolder
C7: 0.1uF; C_1206_3216Metric_Pad1.33x1.80mm_HandSolder
C8: 4.7u; CP_Radial_D8.0mm_P3.50mm
C11, C13, C14: 10u; C_1206_3216Metric_Pad1.33x1.80mm_HandSolder
C12: 1u; C_1206_3216Metric_Pad1.33x1.80mm_HandSolder
C16: 10nF; C_1206_3216Metric_Pad1.33x1.80mm_HandSolder
D1: D_Schottky; D_2010_5025Metric_Pad1.52x2.65mm_HandSolder
J1, J2, J3, J4, J5, J6, J7, J8: 90814-0912; Molex_Picoflex_90814-0012_2x06_P1.27mm_Vertical; Mouser Part Number 538-90814-0912
J9: Debug; PinHeader_1x05_P2.54mm_Vertical
J10: HV_EN; PinHeader_1x02_P2.54mm_Vertical
J11, J16: Conn_01x02_Pin; PinHeader_1x02_P2.54mm_Vertical
J12: Debug1; PinHeader_1x04_P2.54mm_Vertical
J13: 3.3V_EN; PinHeader_1x02_P2.54mm_Vertical
J14: 12V_IN; TerminalBlock_MaiXu_MX126-5.0-02P_1x02_P5.00mm
J15: UART; PinSocket_1x04_P2.54mm_Horizontal
Q1: IPD60R280P7; TO-252-2
Q2, Q3, Q4, Q5: PMV37ENEAR; SOT95P230X110-3N; Mouser Part Number 771-PMV37ENEAR
R1, R2, R3, R4, R5, R6, R7, R8: 18K; R_1206_3216Metric_Pad1.30x1.75mm_HandSolder
R9, R10, R11, R12, R13, R14, R15, R16: 98K; R_1206_3216Metric_Pad1.30x1.75mm_HandSolder
R17, R18, R19, R20: 4.7k; R_1206_3216Metric_Pad1.30x1.75mm_HandSolder
R21: 1M5; R_2010_5025Metric_Pad1.40x2.65mm_HandSolder
R22, R24, R25, R26, R28, R29, R30, R31, R32: 10k; R_1206_3216Metric_Pad1.30x1.75mm_HandSolder
R23: 0R100; R_1210_3225Metric_Pad1.30x2.65mm_HandSolder
R27: 3.6k; R_1206_3216Metric_Pad1.30x1.75mm_HandSolder
RV1: 5K; Potentiometer_Bourns_3296W_Vertical
S1: Reset; TL6150BF160QG; Mouser Part Number 612-TL6150BF160QG
S2: Boot; TL6150BF160QG; Mouser Part Number 612-TL6150BF160QG
SW1: Tog_ON_ON_(ON); Molex_Picoflex_90814-0006_2x03_P1.27mm_Vertical
U1: MAX1771xSA; SO-8_3.9x4.9mm_P1.27mm
U2: TLV76133DCY; SOT-223-3_TabPin2
U3: ESP32-C3-MINI-1
Ur1, Ur2, Ur3: HV5622PG-G; QFP44_10x10MC_MCH-L
Y1: 100uH; AIUR-08; Mouser Part Number 815-AIUR-08-101K

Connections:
+3.3V: C10.1, C11.1, C14.1, J9.1, J15.1, R29.1, R31.1, R32.1, SW1.2 (B), U2.2 (VO), U3.3 (3V3)
+12V: C1.1, C2.1, C3.1, C13.1, J10.2, J13.2, J16.2, R17.1, R18.1, R19.1, R20.1, R22.1, SW1.4 (A), Ur1.27 (*POL), Ur1.30 (VDD), Ur2.27 (*POL), Ur2.30 (VDD), Ur3.27 (*POL), Ur3.30 (VDD)
/ESP_EN: C12.1, R29.2, S1.2 (COM), U3.8 (EN/CHIP_PU)
/LS_BL_in: Q5.1, R22.2, R27.1, U3.18 (GPIO4/ADC1_CH4)
/LS_BL_out: Q5.3, R20.2, Ur1.33 (*BL), Ur2.33 (*BL), Ur3.33 (*BL)
/LS_LE_in: J12.2, Q4.1, R26.1, U3.6 (GPIO3/ADC1_CH3)
/LS_LE_out: Q4.3, R19.2, Ur1.31 (*LE), Ur2.31 (*LE), Ur3.31 (*LE)
/LS_clk_in: J12.3, Q3.1, R24.1, U3.12 (GPIO0/ADC1_CH0/XTAL_32K_P)
/LS_clk_out: Q3.3, R18.2, Ur1.28 (CLK), Ur2.28 (CLK), Ur3.28 (CLK)
/LS_data_in: J12.4, Q2.1, R25.1, U3.13 (GPIO1/ADC1_CH1/XTAL_32K_N)
/LS_data_out: Q2.3, R17.2, Ur1.32 (DATAIN)
/Nixie_1_K0: J1.3 (K0), Ur1.21 (HVOUT2)
/Nixie_1_K1: J1.4 (K1), Ur1.20 (HVOUT3)
/Nixie_1_K2: J1.5 (K2), Ur1.19 (HVOUT4)
/Nixie_1_K3: J1.6 (K3), Ur1.18 (HVOUT5)
/Nixie_1_K4: J1.7 (K4), Ur1.17 (HVOUT6)
/Nixie_1_K5: J1.8 (K5), Ur1.16 (HVOUT7)
/Nixie_1_K6: J1.9 (K6), Ur1.15 (HVOUT8)
/Nixie_1_K7: J1.10 (K7), Ur1.14 (HVOUT9)
/Nixie_1_K8: J1.11 (K8), Ur1.13 (HVOUT10)
/Nixie_1_K9: J1.12 (K9), Ur1.12 (HVOUT11)
/Nixie_2_K0: J2.3 (K0), Ur1.10 (HVOUT13)
/Nixie_2_K1: J2.4 (K1), Ur1.9 (HVOUT14)
/Nixie_2_K2: J2.5 (K2), Ur1.8 (HVOUT15)
/Nixie_2_K3: J2.6 (K3), Ur1.7 (HVOUT16)
/Nixie_2_K4: J2.7 (K4), Ur1.6 (HVOUT17)
/Nixie_2_K5: J2.8 (K5), Ur1.5 (HVOUT18)
/Nixie_2_K6: J2.9 (K6), Ur1.4 (HVOUT19)
/Nixie_2_K7: J2.10 (K7), Ur1.3 (HVOUT20)
/Nixie_2_K8: J2.11 (K8), Ur1.2 (HVOUT21)
/Nixie_2_K9: J2.12 (K9), Ur1.1 (HVOUT22)
/Nixie_3_K0: J5.3 (K0), Ur1.43 (HVOUT24)
/Nixie_3_K1: J5.4 (K1), Ur1.42 (HVOUT25)
/Nixie_3_K2: J5.5 (K2), Ur1.41 (HVOUT26)
/Nixie_3_K3: J5.6 (K3), Ur1.40 (HVOUT27)
/Nixie_3_K4: J5.7 (K4), Ur1.39 (HVOUT28)
/Nixie_3_K5: J5.8 (K5), Ur1.38 (HVOUT29)
/Nixie_3_K6: J5.9 (K6), Ur1.37 (HVOUT30)
/Nixie_3_K7: J5.10 (K7), Ur1.36 (HVOUT31)
/Nixie_3_K8: J5.11 (K8), Ur1.35 (HVOUT32)
/Nixie_3_K9: J5.12 (K9), Ur2.22 (HVOUT1)
/Nixie_4_K0: J6.3 (K0), Ur2.20 (HVOUT3)
/Nixie_4_K1: J6.4 (K1), Ur2.19 (HVOUT4)
/Nixie_4_K2: J6.5 (K2), Ur2.18 (HVOUT5)
/Nixie_4_K3: J6.6 (K3), Ur2.17 (HVOUT6)
/Nixie_4_K4: J6.7 (K4), Ur2.16 (HVOUT7)
/Nixie_4_K5: J6.8 (K5), Ur2.15 (HVOUT8)
/Nixie_4_K6: J6.9 (K6), Ur2.14 (HVOUT9)
/Nixie_4_K7: J6.10 (K7), Ur2.13 (HVOUT10)
/Nixie_4_K8: J6.11 (K8), Ur2.12 (HVOUT11)
/Nixie_4_K9: J6.12 (K9), Ur2.11 (HVOUT12)
/Nixie_5_K0: J7.3 (K0), Ur2.9 (HVOUT14)
/Nixie_5_K1: J7.4 (K1), Ur2.8 (HVOUT15)
/Nixie_5_K2: J7.5 (K2), Ur2.7 (HVOUT16)
/Nixie_5_K3: J7.6 (K3), Ur2.6 (HVOUT17)
/Nixie_5_K4: J7.7 (K4), Ur2.5 (HVOUT18)
/Nixie_5_K5: J7.8 (K5), Ur2.4 (HVOUT19)
/Nixie_5_K6: J7.9 (K6), Ur2.3 (HVOUT20)
/Nixie_5_K7: J7.10 (K7), Ur2.2 (HVOUT21)
/Nixie_5_K8: J7.11 (K8), Ur2.1 (HVOUT22)
/Nixie_5_K9: J7.12 (K9), Ur2.44 (HVOUT23)
/Nixie_6_K0: J8.3 (K0), Ur2.42 (HVOUT25)
/Nixie_6_K1: J8.4 (K1), Ur2.41 (HVOUT26)
/Nixie_6_K2: J8.5 (K2), Ur2.40 (HVOUT27)
/Nixie_6_K3: J8.6 (K3), Ur2.39 (HVOUT28)
/Nixie_6_K4: J8.7 (K4), Ur2.38 (HVOUT29)
/Nixie_6_K5: J8.8 (K5), Ur2.37 (HVOUT30)
/Nixie_6_K6: J8.9 (K6), Ur2.36 (HVOUT31)
/Nixie_6_K7: J8.10 (K7), Ur2.35 (HVOUT32)
/Nixie_6_K8: J8.11 (K8), Ur3.22 (HVOUT1)
/Nixie_6_K9: J8.12 (K9), Ur3.21 (HVOUT2)
/Nixie_7_K0: J3.3 (K0), Ur3.19 (HVOUT4)
/Nixie_7_K1: J3.4 (K1), Ur3.18 (HVOUT5)
/Nixie_7_K2: J3.5 (K2), Ur3.17 (HVOUT6)
/Nixie_7_K3: J3.6 (K3), Ur3.16 (HVOUT7)
/Nixie_7_K4: J3.7 (K4), Ur3.15 (HVOUT8)
/Nixie_7_K5: J3.8 (K5), Ur3.14 (HVOUT9)
/Nixie_7_K6: J3.9 (K6), Ur3.13 (HVOUT10)
/Nixie_7_K7: J3.10 (K7), Ur3.12 (HVOUT11)
/Nixie_7_K8: J3.11 (K8), Ur3.11 (HVOUT12)
/Nixie_7_K9: J3.12 (K9), Ur3.10 (HVOUT13)
/Nixie_8_K0: J4.3 (K0), J9.2, Ur3.8 (HVOUT15)
/Nixie_8_K1: J4.4 (K1), J9.3, Ur3.7 (HVOUT16)
/Nixie_8_K2: J4.5 (K2), J9.4, Ur3.6 (HVOUT17)
/Nixie_8_K3: J4.6 (K3), Ur3.5 (HVOUT18)
/Nixie_8_K4: J4.7 (K4), Ur3.4 (HVOUT19)
/Nixie_8_K5: J4.8 (K5), Ur3.3 (HVOUT20)
/Nixie_8_K6: J4.9 (K6), Ur3.2 (HVOUT21)
/Nixie_8_K7: J4.10 (K7), Ur3.1 (HVOUT22)
/Nixie_8_K8: J4.11 (K8), Ur3.44 (HVOUT23)
/Nixie_8_K9: J4.12 (K9), Ur3.43 (HVOUT24)
/PU_GPIO2: R31.2, U3.5 (GPIO2/ADC1_CH2)
/PU_GPIO8: R32.2, U3.22 (GPIO8)
/boot_dl: C16.1, S2.2 (COM), U3.23 (GPIO9)
/mode_sel: C15.1, R30.1, SW1.1 (A), U3.19 (GPIO5/ADC2_CH0)
GND: C1.2, C2.2, C3.2, C4.2, C6.2, C7.2, C8.2, C9.2, C10.2, C11.2, C12.2, C13.2, C14.2, C15.2, C16.2, J9.5, J12.1, J14.2, J15.4, J16.1, Q2.2, Q3.2, Q4.2, Q5.2, R23.2, R24.2, R25.2, R26.2, R27.2, R28.2, R30.2, S1.4 (NO), S2.4 (NO), U1.4 (SHDN), U1.6 (AGND), U1.7 (GND), U2.1 (GND), U3.1 (GND), U3.2 (GND), U3.11 (GND), U3.14 (GND), U3.36 (GND), U3.37 (GND), U3.38 (GND), U3.39 (GND), U3.40 (GND), U3.41 (GND), U3.42 (GND), U3.43 (GND), U3.44 (GND), U3.45 (GND), U3.46 (GND), U3.47 (GND), U3.48 (GND), U3.49 (GND), U3.50 (GND), U3.51 (GND), U3.52 (GND), U3.53 (GND), Ur1.29 (VSS), Ur2.29 (VSS), Ur3.29 (VSS)
HT: J11.1, R1.2, R2.2, R3.2, R4.2, R5.2, R6.2, R7.2, R8.2
unnamed: D1.2 (A), Q1.2 (D), Y1.4
unnamed: C7.1, C8.1, D1.1 (K), J11.2, R21.1
unnamed: J1.1 (A), R8.1
unnamed: J1.2 (C), R13.1
unnamed: J2.1 (A), R7.1
unnamed: J2.2 (C), R14.1
unnamed: J3.1 (A), R1.1
unnamed: J3.2 (C), R11.1
unnamed: J4.1 (A), R2.1
unnamed: J4.2 (C), R12.1
unnamed: J5.1 (A), R3.1
unnamed: J5.2 (C), R15.1
unnamed: J6.1 (A), R4.1
unnamed: J6.2 (C), R16.1
unnamed: J7.1 (A), R5.1
unnamed: J7.2 (C), R9.1
unnamed: J8.1 (A), R6.1
unnamed: J8.2 (C), R10.1
unnamed: C4.1, C6.1, J10.1, U1.2 (V+), Y1.2
unnamed: J13.1, U2.3 (VI)
unnamed: J14.1, SW1.5 (B)
unnamed: J15.2, U3.30 (GPIO20/U0RXD)
unnamed: J15.3, U3.31 (GPIO21/U0TXD)
unnamed: Q1.1 (G), U1.1 (EXT)
unnamed: Q1.3 (S), R23.1, U1.8 (CS)
unnamed: R28.1, RV1.2, RV1.3
unnamed: R21.2, RV1.1, U1.3 (FB)
unnamed: C9.1, U1.5 (REF)
unnamed: Ur1.23 (DATAOUT), Ur2.32 (DATAIN)
unnamed: R13.2, Ur1.22 (HVOUT1)
unnamed: R14.2, Ur1.11 (HVOUT12)
unnamed: R15.2, Ur1.44 (HVOUT23)
unnamed: Ur2.23 (DATAOUT), Ur3.32 (DATAIN)
unnamed: R16.2, Ur2.21 (HVOUT2)
unnamed: R9.2, Ur2.10 (HVOUT13)
unnamed: R10.2, Ur2.43 (HVOUT24)
unnamed: R11.2, Ur3.20 (HVOUT3)
unnamed: R12.2, Ur3.9 (HVOUT14)

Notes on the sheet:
Nixie clock controller Theo Lephay 12/2025
HV DCDC
Power & mode toggle switch
LS_BL_out low by default so that all shift register outputs are off
Boot strapping pins
Level shifters

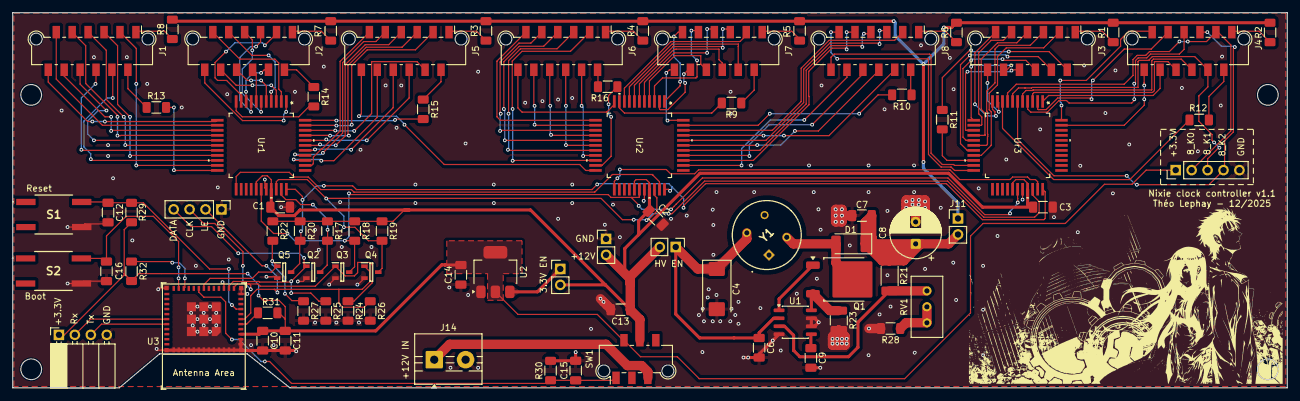
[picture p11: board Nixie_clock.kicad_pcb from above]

Board: 2 copper layers, 203.2 x 59.8 mm, 80 parts (0 on the bottom side), 135 nets.

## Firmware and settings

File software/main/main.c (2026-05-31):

#include "freertos/FreeRTOS.h"
#include "freertos/task.h"
#include <stdio.h>
#include "NixieDisplay.h"
#include "ModeSwitch.h"
#include "SmartClock.h"
#include "Connectivity.h"
#include "driver/gpio.h"


void app_main(void)
{
    printf("Start\n");

    NixieDisplay_Init();
    ModeSwitch_init();
    Clock_Init();
    Connectivity_Init();

    BaseType_t ret = xTaskCreate(
        Clock_Task,
        "Clock task",
        2048,
        NULL,
        2, // lower number lower prio
        &clockTaskHandle
    );
    if (ret != pdPASS){
        printf("clock task creation failed");
        esp_restart();
    }

    ret = xTaskCreate(
        ModeSwitch_Task,
        "Switch task",
        2048,
        NULL,
        3,
        &switchTaskHandle
    );
    if (ret != pdPASS){
        printf("modeSwitch task creation failed");
        esp_restart();
    }

    ret = xTaskCreate(
        Connectivity_Task,
        "Connectivity_Task",
        2048,
        NULL,
        4,
        NULL);
    if (ret != pdPASS){
        printf("connectivity task creation failed");
        esp_restart();
    }

}

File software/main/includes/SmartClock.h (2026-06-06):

#ifndef SMARTCLOCK_H
#define SMARTCLOCK_H

#include "freertos/FreeRTOS.h"
#include "freertos/task.h"

extern TaskHandle_t clockTaskHandle;

#define NTF_CHANGE_MODE_PRESS 0u
#define NTF_POWER_TUBES_PRESS  1u
#define NTF_NTC_UPDATE         2u
#define NTF_MAINTENANCE        3u
#define NTF_TURN_ON            4u
#define NTF_TURN_OFF           5u

#define NTF_CHANGE_MODE_MSK        (1u << NTF_CHANGE_MODE_PRESS)
#define NTF_POWER_TUBES_MSK        (1u << NTF_POWER_TUBES_PRESS)
#define NTF_NTC_UPDATE_MSK         (1u << NTF_NTC_UPDATE)
#define NTF_MAINTENANCE_MSK        (1u << NTF_MAINTENANCE)
#define NTF_TURN_ON_MSK            (1u << NTF_TURN_ON)
#define NTF_TURN_OFF_MSK           (1u << NTF_TURN_OFF)

// Ratio is 0.2s:60s. TODO make this smarter smarter
#define MAINTENANCE_DURATION_S 1u
#define MAINTENANCE_INTERVAL_S (MAINTENANCE_DURATION_S * 300)

#define SCHEDULE_POINTS_PER_DAY 4u
#define DAYS_PER_WEEK           7u
#define UNDEF_HOUR              24u

typedef enum
{
    CLOCK_STATE_POWER_OFF,
    CLOCK_STATE_WAIT_TIME,  // Wait for real time update from NTP server (on boot)
    CLOCK_STATE_TIME,       // Display current time
    CLOCK_STATE_ROLL,       // Display current time
    CLOCK_STATE_RANDOM,     // Display random digits
    CLOCK_STATE_STEINS,     // Steins gate animation
    CLOCK_STATE_STATE_MAX
} ClockState_t;


void Clock_Task(void *arg);
void Clock_Init(void);


#endif

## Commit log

2026-01-28 Hardware revision 1.1
    Fix: HV5622 pad spacing, use bigger DCDC FET, add LS NFETs PD resistors, Minor layout fixes.
    [Nixie_clock.kicad_pcb, Nixie_clock.kicad_sch]
2026-09-13 Update README
    Added information about the use of original IN-14 Nixie tubes.
